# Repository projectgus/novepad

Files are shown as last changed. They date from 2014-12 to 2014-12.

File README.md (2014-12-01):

Development of an adapter board design for [Kosagi Novena](http://kosagi.com/w/index.php?title=Novena_Main_Page) LVDS interface to connect to the "iPad 3" QXGA 2048x1536 eDP LCD panel (aka LG LP097QX1-SPC1 and related models). Possibly also a touch screen interface to suit that display...

* [Schematic PDF here](https://github.com/projectgus/novepad/raw/master/novepad-schematic.pdf)
* [Kosagi forum thread here](http://www.kosagi.com/forums/viewtopic.php?id=58).

**INITIAL PROTOTYPE STAGE, NOT A THING YET**

Very closely modelled on Bunnie's existing Novena eDP adapter, with additions. LVDS connection cable from Novena should be the same on both boards.

Designed using KiCad (2014-07-25, any recent version should be OK to open the files). [Gerbers are available from the releases page](https://github.com/projectgus/novepad/releases/).

# Additions to the Novena eDP design

* Backlight driver (2x TI [TPS61181](http://www.ti.com/product/tps61181))
* Touch screen controller Focaltech [FT5816LPC](http://www.focaltech-systems.com/En/solutions.aspx?CateID=54) with i2c and USB interfaces. There's a strong chance this will never work (lack of public documentation on controller or digitizer).
* 4 eDP lanes out of IT6251 eDP converter instead of the 2 used on Novena eDP board.

# Notes

* Has a lot of numbered test points and 0R resistors due to undocumented or unknown factors.
* Has cut trace jumpers for some key power connections, can be cut to measure power consumption.

# Board Stackup

4 layer board, 1oz copper (35um). Desired stackup is:

* Front copper
* 0.2mm prepreg
* GND (Inner1)
* 1.2mm prepreg
* VCC (Inner2)
* 0.2mm prepreg
* Back

(This matches standard 4 layer stackup for my usual prototype PCB supplier, [Hackvana](http://hackvana.com)).)

The 100 ohm differential microstrip traces (LVDS, eDP) are routed as 0.2mm trace / 0.15mm spacing (~8/6 imperial), at least where possible. This yields estimates in the range of 99.5-102ohm differential impedance depending on who you ask (assuming Er 4.4, calculated using [TNT Field Solver](http://mmtl.sourceforge.net/) and [Jean Nicolle's impedance calculator](http://www.fedevel.com/welldoneblog/2011/08/pcb-impedance-calculator-single-ended-differential-pair/).

# Resources

## Novena designs

Yay OSHW!

* http://kosagi.com/w/index.php?title=Novena_PVT_Design_Source

## iPad display/connectors

* http://emerythacks.blogspot.com.au/2013/04/connecting-ipad-retina-lcd-to-pc.html
* http://mikesmods.com/mm-wp/?s=ipad+3

## Photos of IT6251

You know a chip is going to be fun when **photos** of PCBs that use it become a useful resource to complement the datasheet.

* [overclock.net post with high-res photo of top of board](http://www.overclock.net/t/1225919/yamakasi-catleap-monitor-club/2110#post_16887300)
* [overclock.net lower-res photos incl back of board (no components)](http://www.overclock.net/t/1304102/catleap-q270-replacement-board#post_18163044)

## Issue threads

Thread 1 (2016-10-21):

{Question} Functional?

felixekman, 2016-10-21:
Did you ever get this to work with touch? Can't find a definitive statement about it.

projectgus, 2016-10-21:
No. :( The thread on kosagi forums has some details from back when I was working on it:
http://www.kosagi.com/forums/viewtopic.php?id=58

Summary:

* The Focaltech touch chip doesn't appear to work at all without firmware, which I didn't have. Company & the distributors I found never answered my emails (understandable), and I couldn't find anything suitable in random android file drops, etc.
* I couldn't find any other captouch chips that seemed suitable (in particular, there arelots of touch channels on the ipad3 touch screens).

It's been a couple of years though, so something newer and more suitable might exist now. Another thing to possibly try is to find another model capacitive touch digitiser of the same size, maybe one from a 10 inch Android tablet where the digitiser chip is integrated into the screen unit and it just speaks i2c or something...

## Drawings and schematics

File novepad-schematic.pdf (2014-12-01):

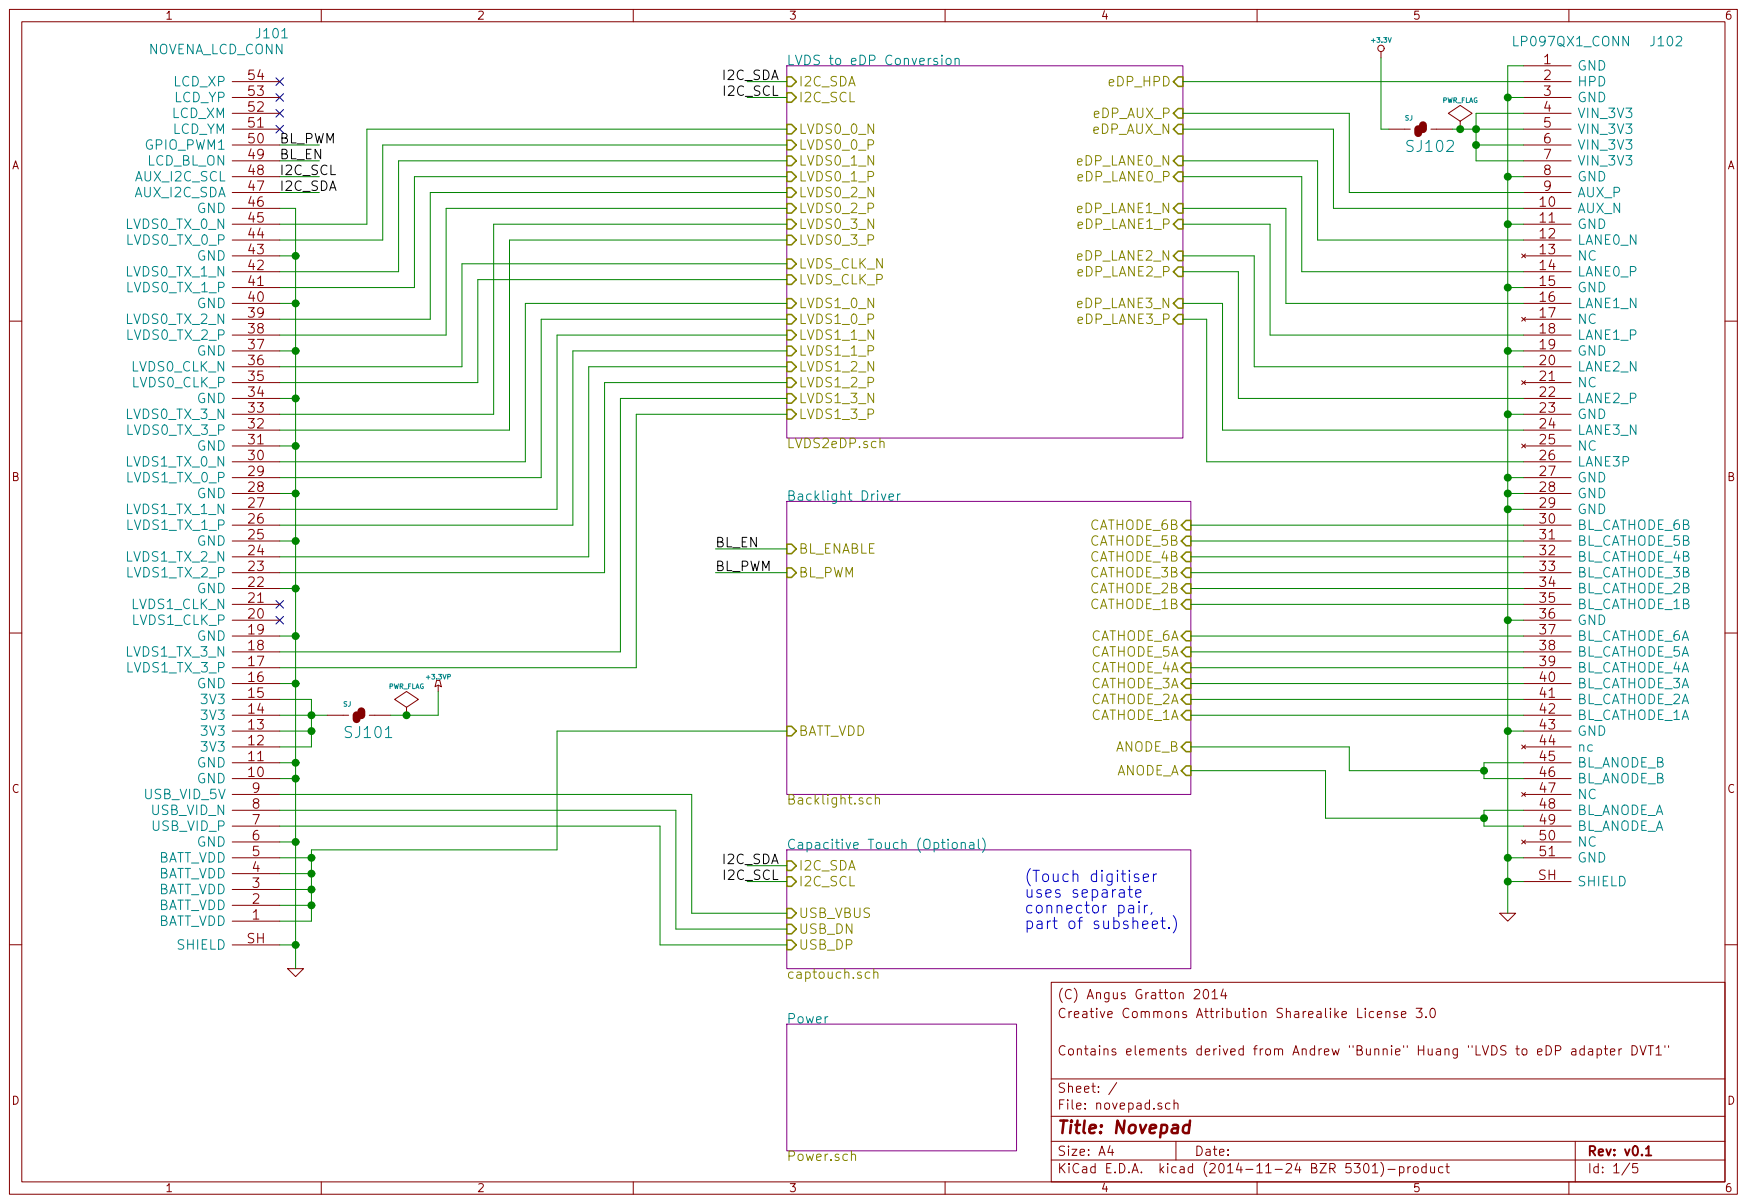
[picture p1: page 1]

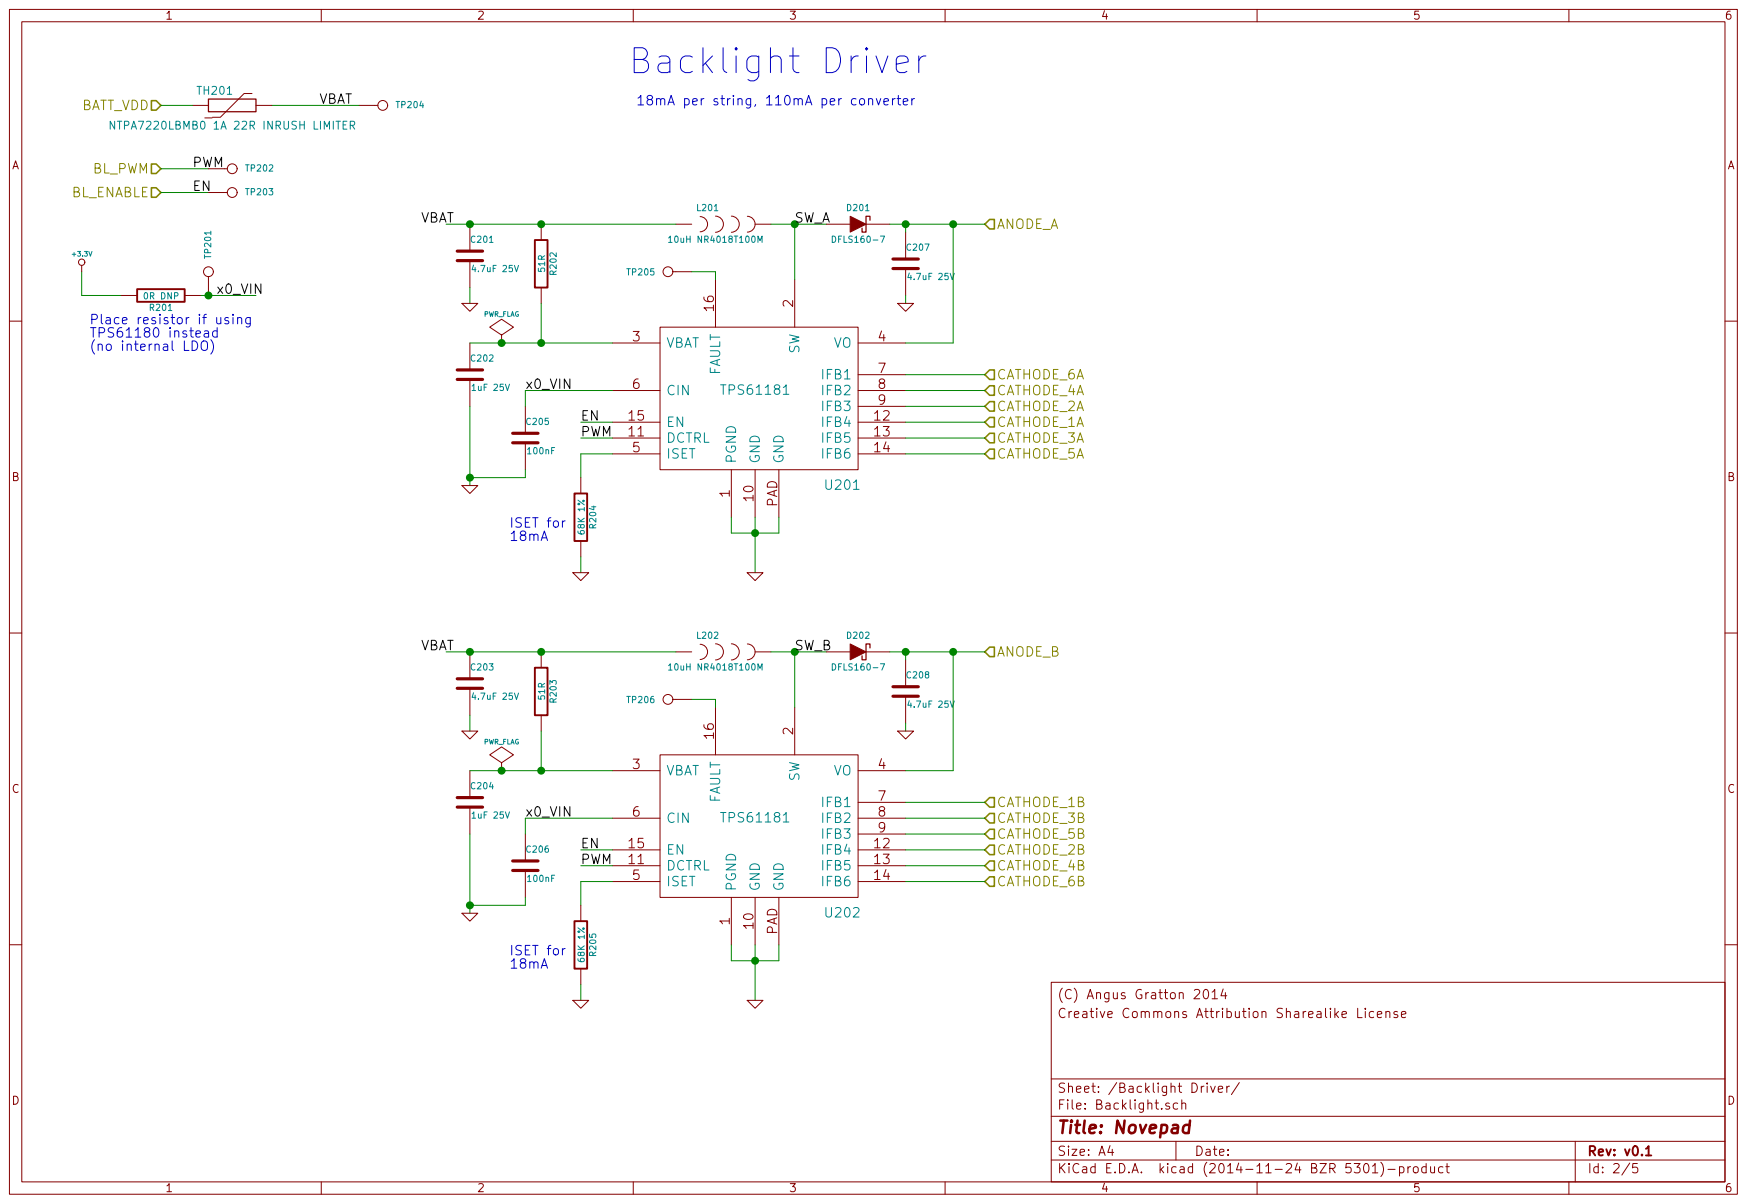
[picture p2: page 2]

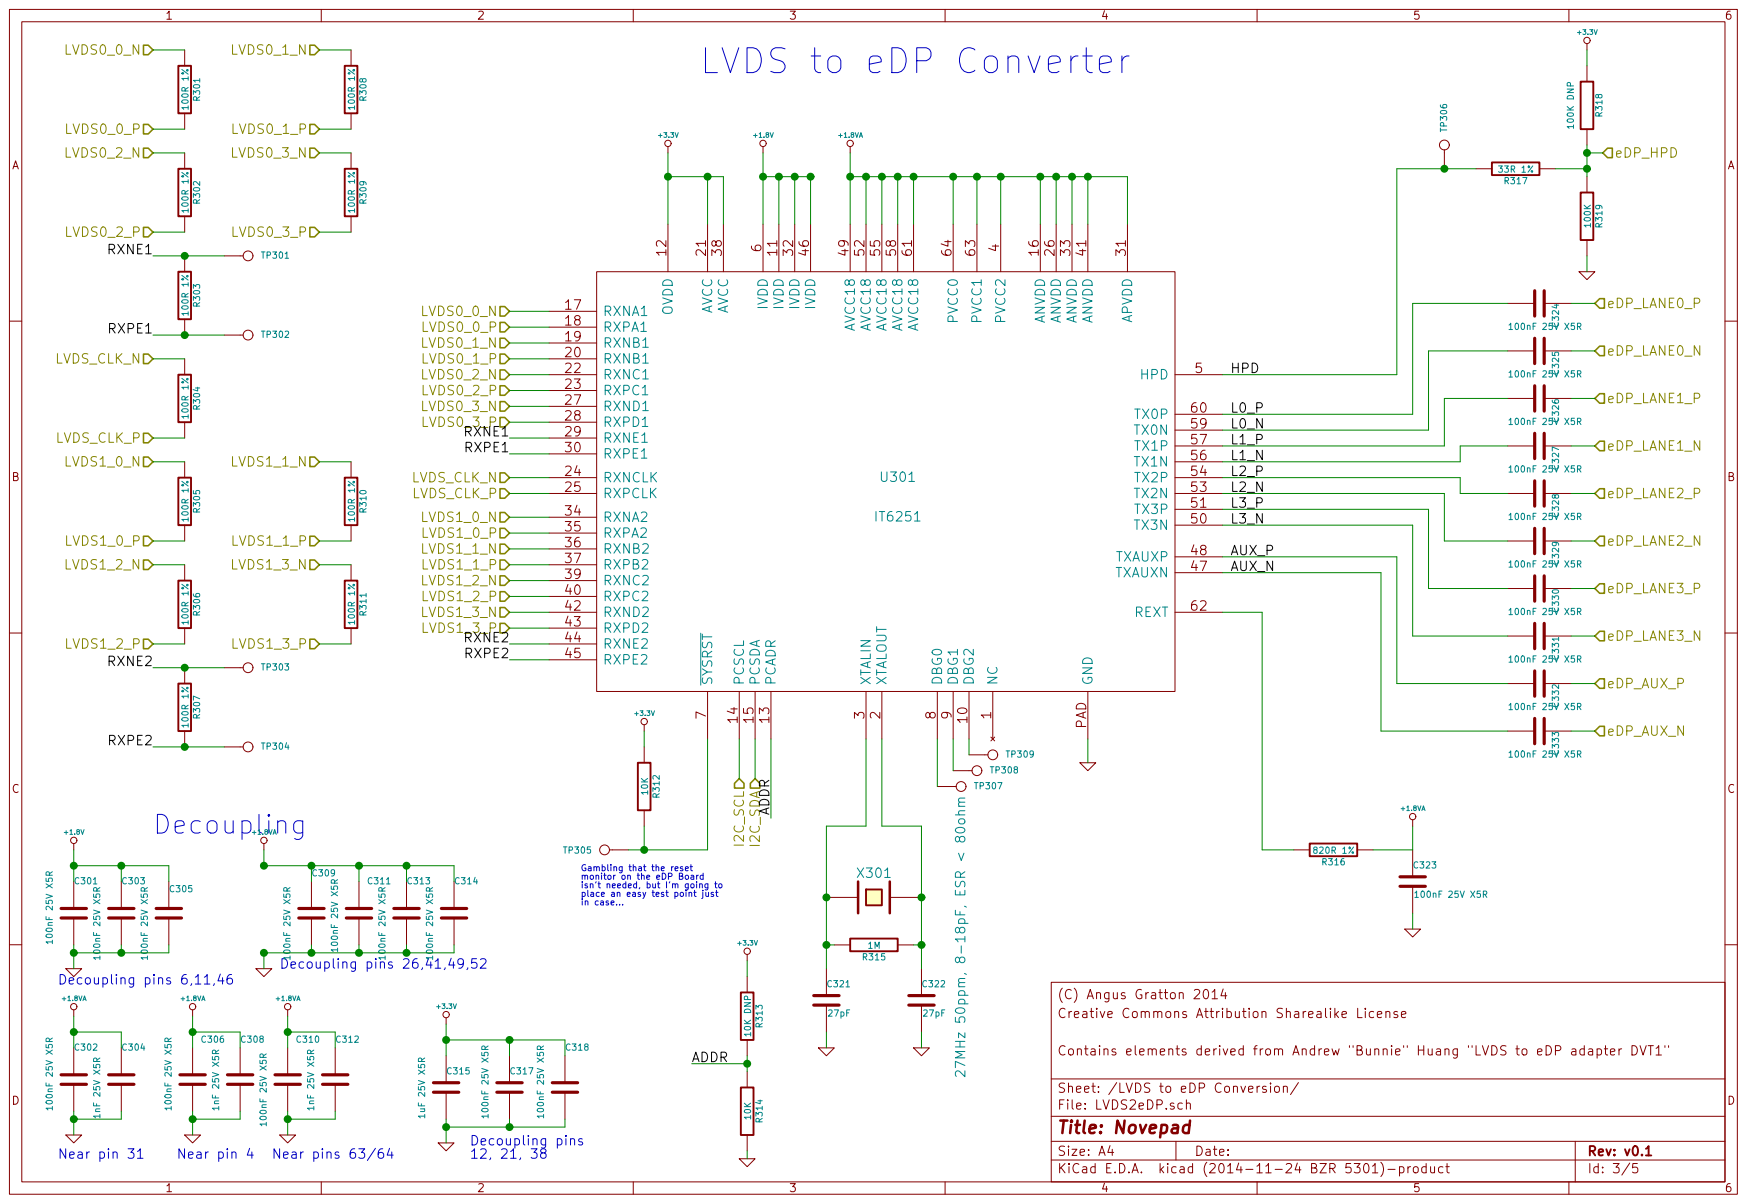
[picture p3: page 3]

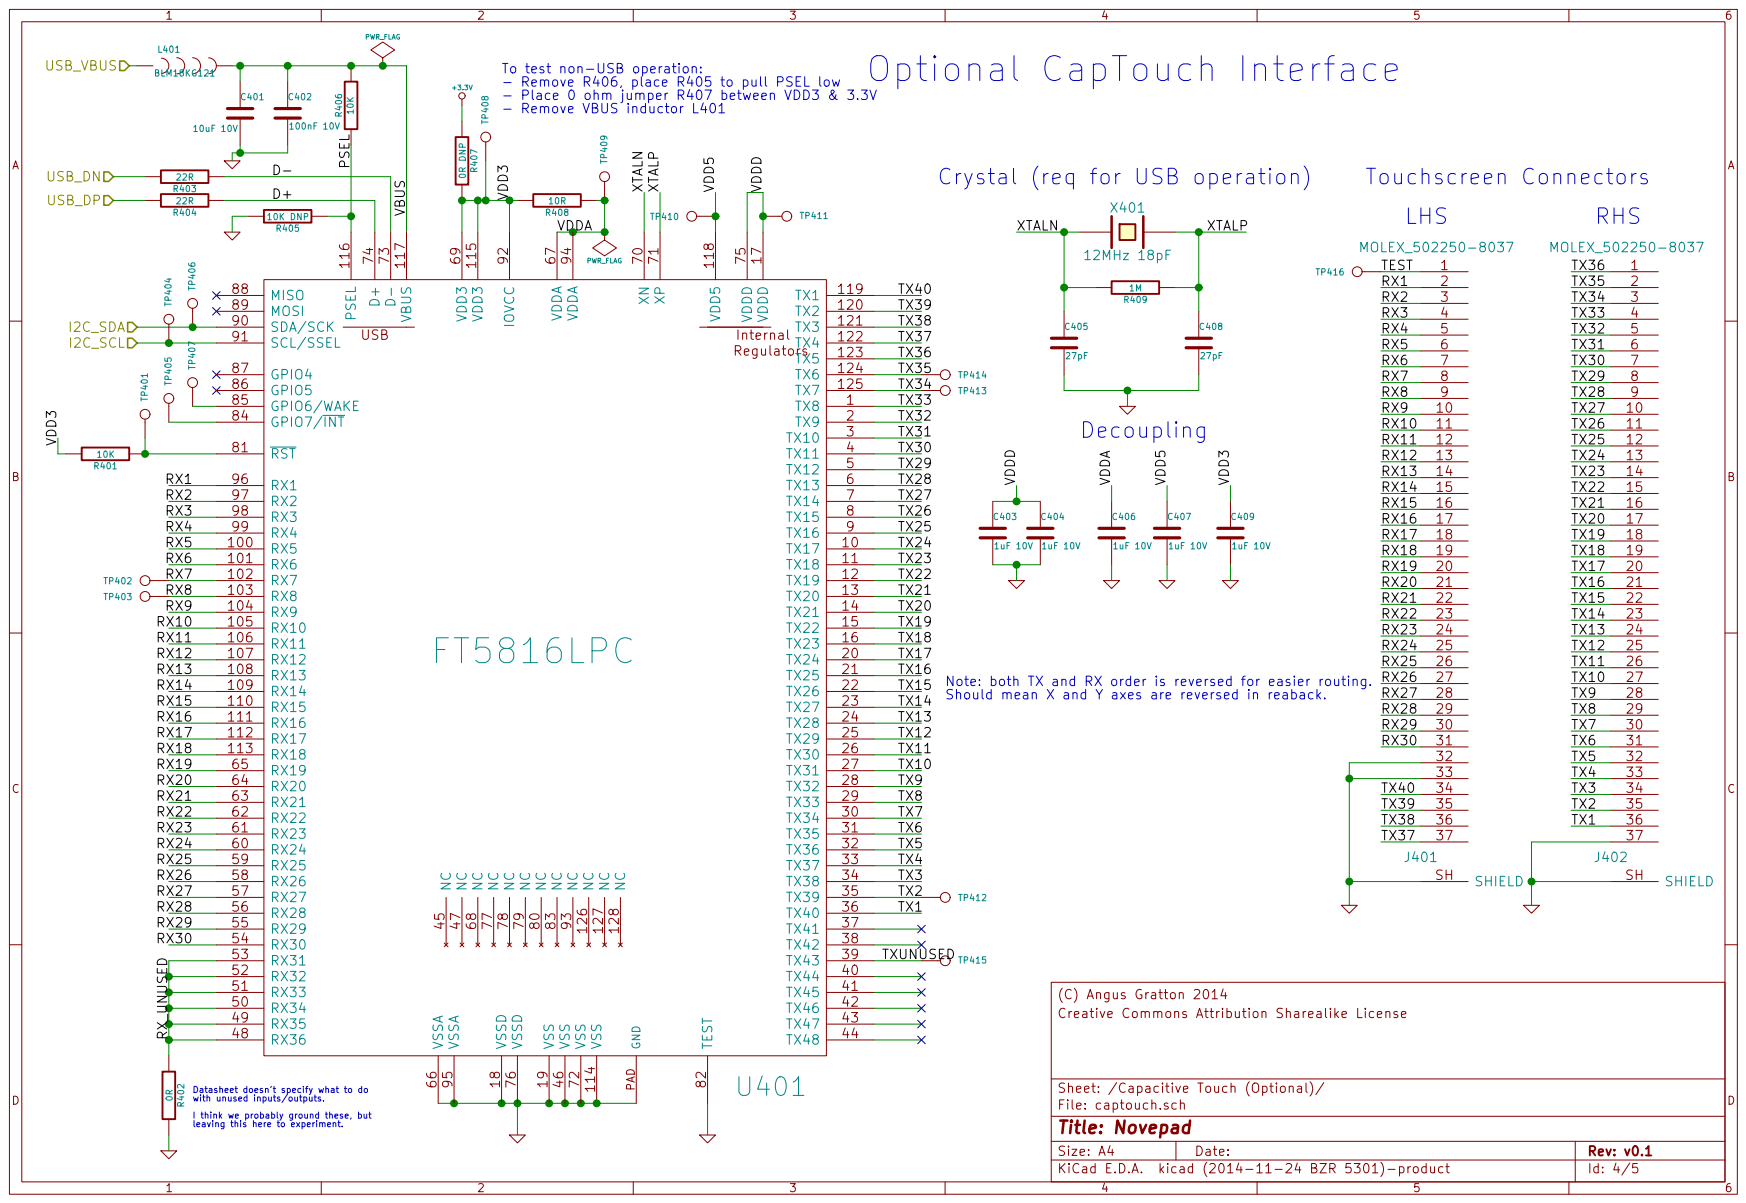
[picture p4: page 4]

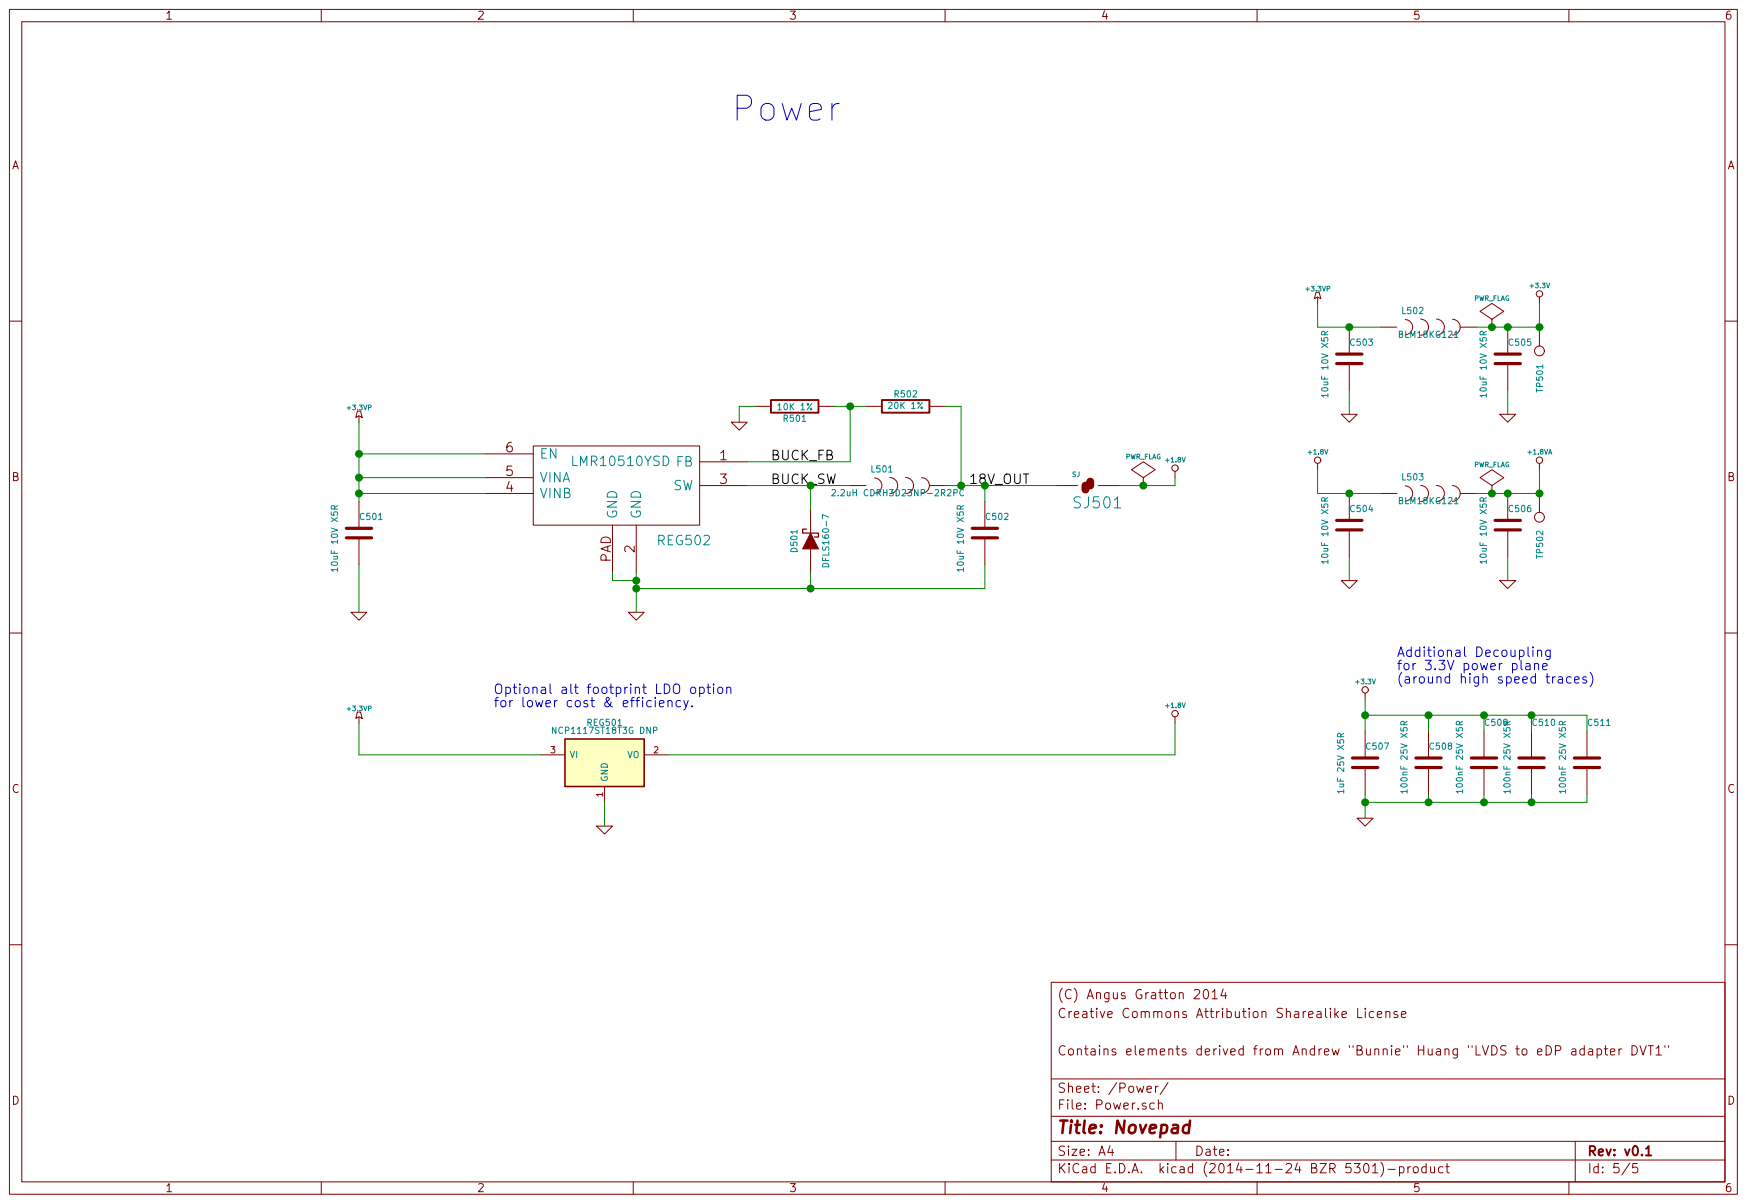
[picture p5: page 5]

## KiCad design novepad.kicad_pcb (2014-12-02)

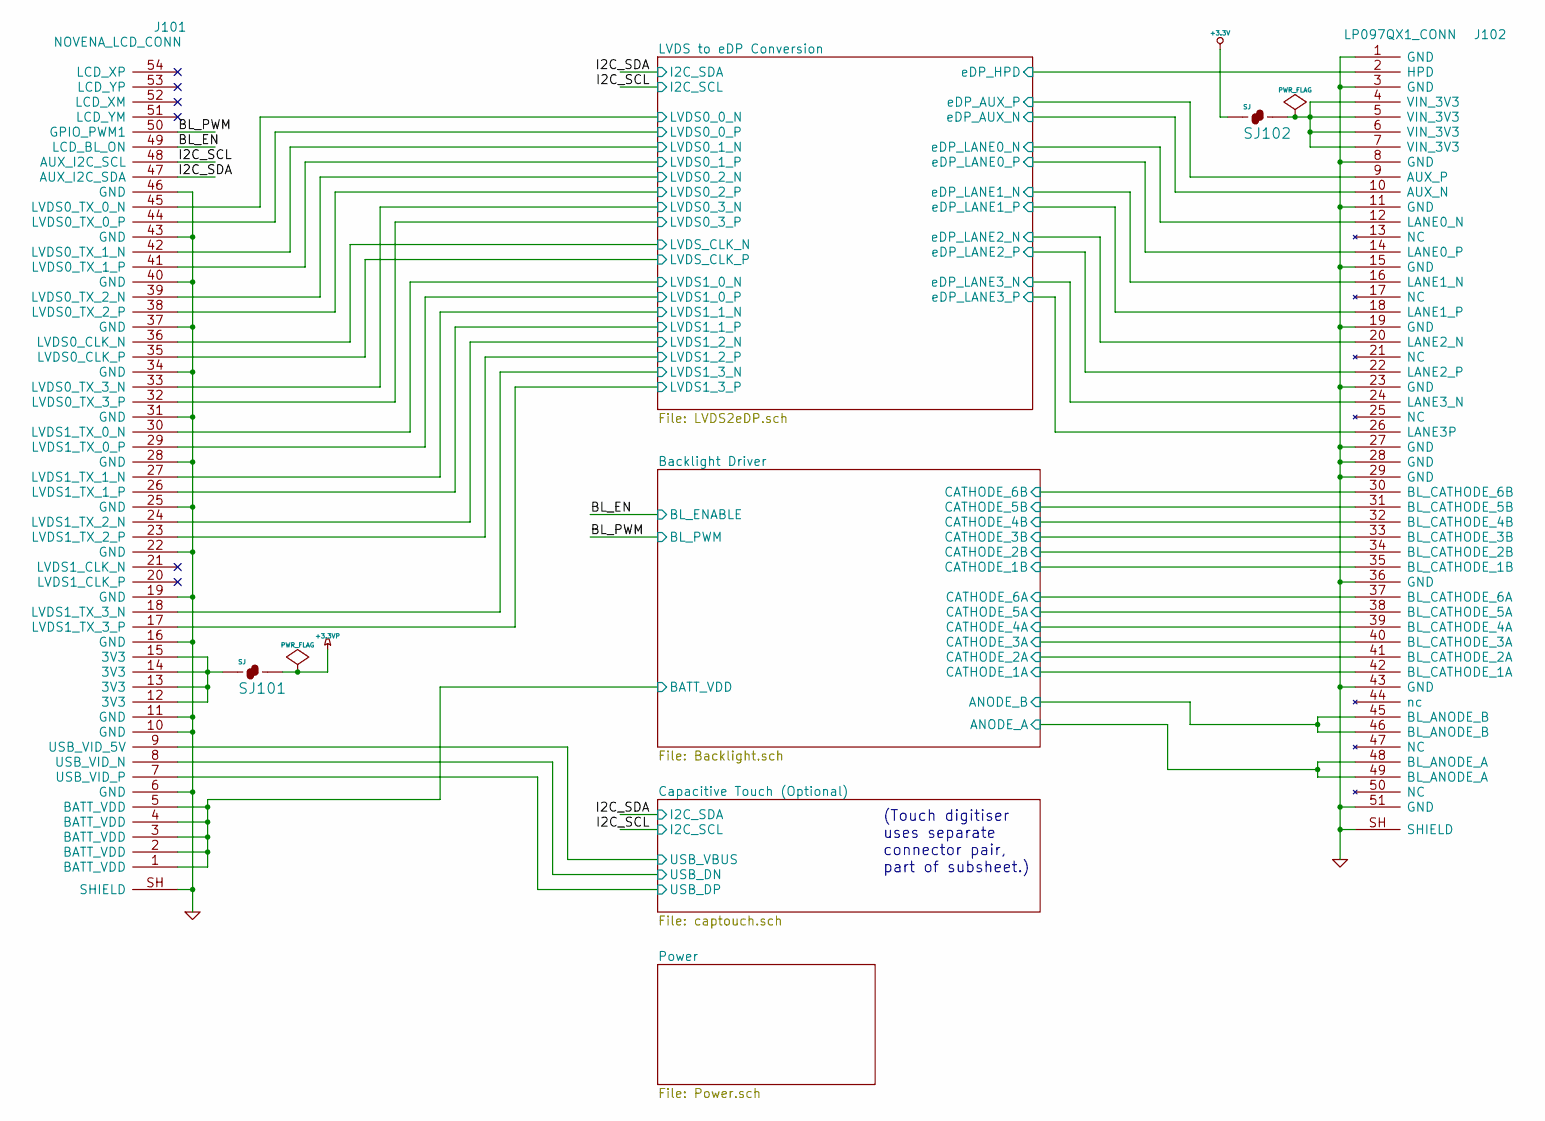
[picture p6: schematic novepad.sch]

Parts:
J101: NOVENA_LCD_CONN; MOLEX_51926_5494
J102: LP097QX1_CONN; MOLEX_502250_8051
SJ101, SJ102: SJ; SJ_SHORTED

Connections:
+3.3V: SJ102.1; also elsewhere on the board
+3.3VP: SJ101.2; also elsewhere on the board
/Backlight Driver/ANODE_A: J102.48 (BL_ANODE_A), J102.49 (BL_ANODE_A); also elsewhere on the board
/Backlight Driver/ANODE_B: J102.45 (BL_ANODE_B), J102.46 (BL_ANODE_B); also elsewhere on the board
/Backlight Driver/BATT_VDD: J101.1 (BATT_VDD), J101.2 (BATT_VDD), J101.3 (BATT_VDD), J101.4 (BATT_VDD), J101.5 (BATT_VDD); also elsewhere on the board
/Backlight Driver/BL_ENABLE: J101.49 (LCD_BL_ON); also elsewhere on the board
/Backlight Driver/BL_PWM: J101.50 (GPIO_PWM1); also elsewhere on the board
/Backlight Driver/CATHODE_1A: J102.42 (BL_CATHODE_1A); also elsewhere on the board
/Backlight Driver/CATHODE_1B: J102.35 (BL_CATHODE_1B); also elsewhere on the board
/Backlight Driver/CATHODE_2A: J102.41 (BL_CATHODE_2A); also elsewhere on the board
/Backlight Driver/CATHODE_2B: J102.34 (BL_CATHODE_2B); also elsewhere on the board
/Backlight Driver/CATHODE_3A: J102.40 (BL_CATHODE_3A); also elsewhere on the board
/Backlight Driver/CATHODE_3B: J102.33 (BL_CATHODE_3B); also elsewhere on the board
/Backlight Driver/CATHODE_4A: J102.39 (BL_CATHODE_4A); also elsewhere on the board
/Backlight Driver/CATHODE_4B: J102.32 (BL_CATHODE_4B); also elsewhere on the board
/Backlight Driver/CATHODE_5A: J102.38 (BL_CATHODE_5A); also elsewhere on the board
/Backlight Driver/CATHODE_5B: J102.31 (BL_CATHODE_5B); also elsewhere on the board
/Backlight Driver/CATHODE_6A: J102.37 (BL_CATHODE_6A); also elsewhere on the board
/Backlight Driver/CATHODE_6B: J102.30 (BL_CATHODE_6B); also elsewhere on the board
/Capacitive Touch (Optional)/I2C_SCL: J101.48 (AUX_I2C_SCL); also elsewhere on the board
/Capacitive Touch (Optional)/I2C_SDA: J101.47 (AUX_I2C_SDA); also elsewhere on the board
/Capacitive Touch (Optional)/USB_DN: J101.8 (USB_VID_N); also elsewhere on the board
/Capacitive Touch (Optional)/USB_DP: J101.7 (USB_VID_P); also elsewhere on the board
/Capacitive Touch (Optional)/USB_VBUS: J101.9 (USB_VID_5V); also elsewhere on the board
/LVDS to eDP Conversion/LVDS0_0_N: J101.45 (LVDS0_TX_0_N); also elsewhere on the board
/LVDS to eDP Conversion/LVDS0_0_P: J101.44 (LVDS0_TX_0_P); also elsewhere on the board
/LVDS to eDP Conversion/LVDS0_1_N: J101.42 (LVDS0_TX_1_N); also elsewhere on the board
/LVDS to eDP Conversion/LVDS0_1_P: J101.41 (LVDS0_TX_1_P); also elsewhere on the board
/LVDS to eDP Conversion/LVDS0_2_N: J101.39 (LVDS0_TX_2_N); also elsewhere on the board
/LVDS to eDP Conversion/LVDS0_2_P: J101.38 (LVDS0_TX_2_P); also elsewhere on the board
/LVDS to eDP Conversion/LVDS0_3_N: J101.33 (LVDS0_TX_3_N); also elsewhere on the board
/LVDS to eDP Conversion/LVDS0_3_P: J101.32 (LVDS0_TX_3_P); also elsewhere on the board
/LVDS to eDP Conversion/LVDS1_0_N: J101.30 (LVDS1_TX_0_N); also elsewhere on the board
/LVDS to eDP Conversion/LVDS1_0_P: J101.29 (LVDS1_TX_0_P); also elsewhere on the board
/LVDS to eDP Conversion/LVDS1_1_N: J101.27 (LVDS1_TX_1_N); also elsewhere on the board
/LVDS to eDP Conversion/LVDS1_1_P: J101.26 (LVDS1_TX_1_P); also elsewhere on the board
/LVDS to eDP Conversion/LVDS1_2_N: J101.24 (LVDS1_TX_2_N); also elsewhere on the board
/LVDS to eDP Conversion/LVDS1_2_P: J101.23 (LVDS1_TX_2_P); also elsewhere on the board
/LVDS to eDP Conversion/LVDS1_3_N: J101.18 (LVDS1_TX_3_N); also elsewhere on the board
/LVDS to eDP Conversion/LVDS1_3_P: J101.17 (LVDS1_TX_3_P); also elsewhere on the board
/LVDS to eDP Conversion/LVDS_CLK_N: J101.36 (LVDS0_CLK_N); also elsewhere on the board
/LVDS to eDP Conversion/LVDS_CLK_P: J101.35 (LVDS0_CLK_P); also elsewhere on the board
/LVDS to eDP Conversion/eDP_AUX_N: J102.10 (AUX_N); also elsewhere on the board
/LVDS to eDP Conversion/eDP_AUX_P: J102.9 (AUX_P); also elsewhere on the board
/LVDS to eDP Conversion/eDP_HPD: J102.2 (HPD); also elsewhere on the board
/LVDS to eDP Conversion/eDP_LANE0_N: J102.12 (LANE0_N); also elsewhere on the board
/LVDS to eDP Conversion/eDP_LANE0_P: J102.14 (LANE0_P); also elsewhere on the board
/LVDS to eDP Conversion/eDP_LANE1_N: J102.16 (LANE1_N); also elsewhere on the board
/LVDS to eDP Conversion/eDP_LANE1_P: J102.18 (LANE1_P); also elsewhere on the board
/LVDS to eDP Conversion/eDP_LANE2_N: J102.20 (LANE2_N); also elsewhere on the board
/LVDS to eDP Conversion/eDP_LANE2_P: J102.22 (LANE2_P); also elsewhere on the board
/LVDS to eDP Conversion/eDP_LANE3_N: J102.24 (LANE3_N); also elsewhere on the board
/LVDS to eDP Conversion/eDP_LANE3_P: J102.26 (LANE3P); also elsewhere on the board
GND: J101.6 (GND), J101.10 (GND), J101.11 (GND), J101.16 (GND), J101.19 (GND), J101.22 (GND), J101.25 (GND), J101.28 (GND), J101.31 (GND), J101.34 (GND), J101.37 (GND), J101.40 (GND), J101.43 (GND), J101.46 (GND), J101.SH (SHIELD), J102.1 (GND), J102.3 (GND), J102.8 (GND), J102.11 (GND), J102.15 (GND), J102.19 (GND), J102.23 (GND), J102.27 (GND), J102.28 (GND), J102.29 (GND), J102.36 (GND), J102.43 (GND), J102.51 (GND), J102.SH (SHIELD); also elsewhere on the board
unnamed: J101.12 (3V3), J101.13 (3V3), J101.14 (3V3), J101.15 (3V3), SJ101.1
unnamed: J102.4 (VIN_3V3), J102.5 (VIN_3V3), J102.6 (VIN_3V3), J102.7 (VIN_3V3), SJ102.2

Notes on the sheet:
(Touch digitiser uses separate connector pair, part of subsheet.)

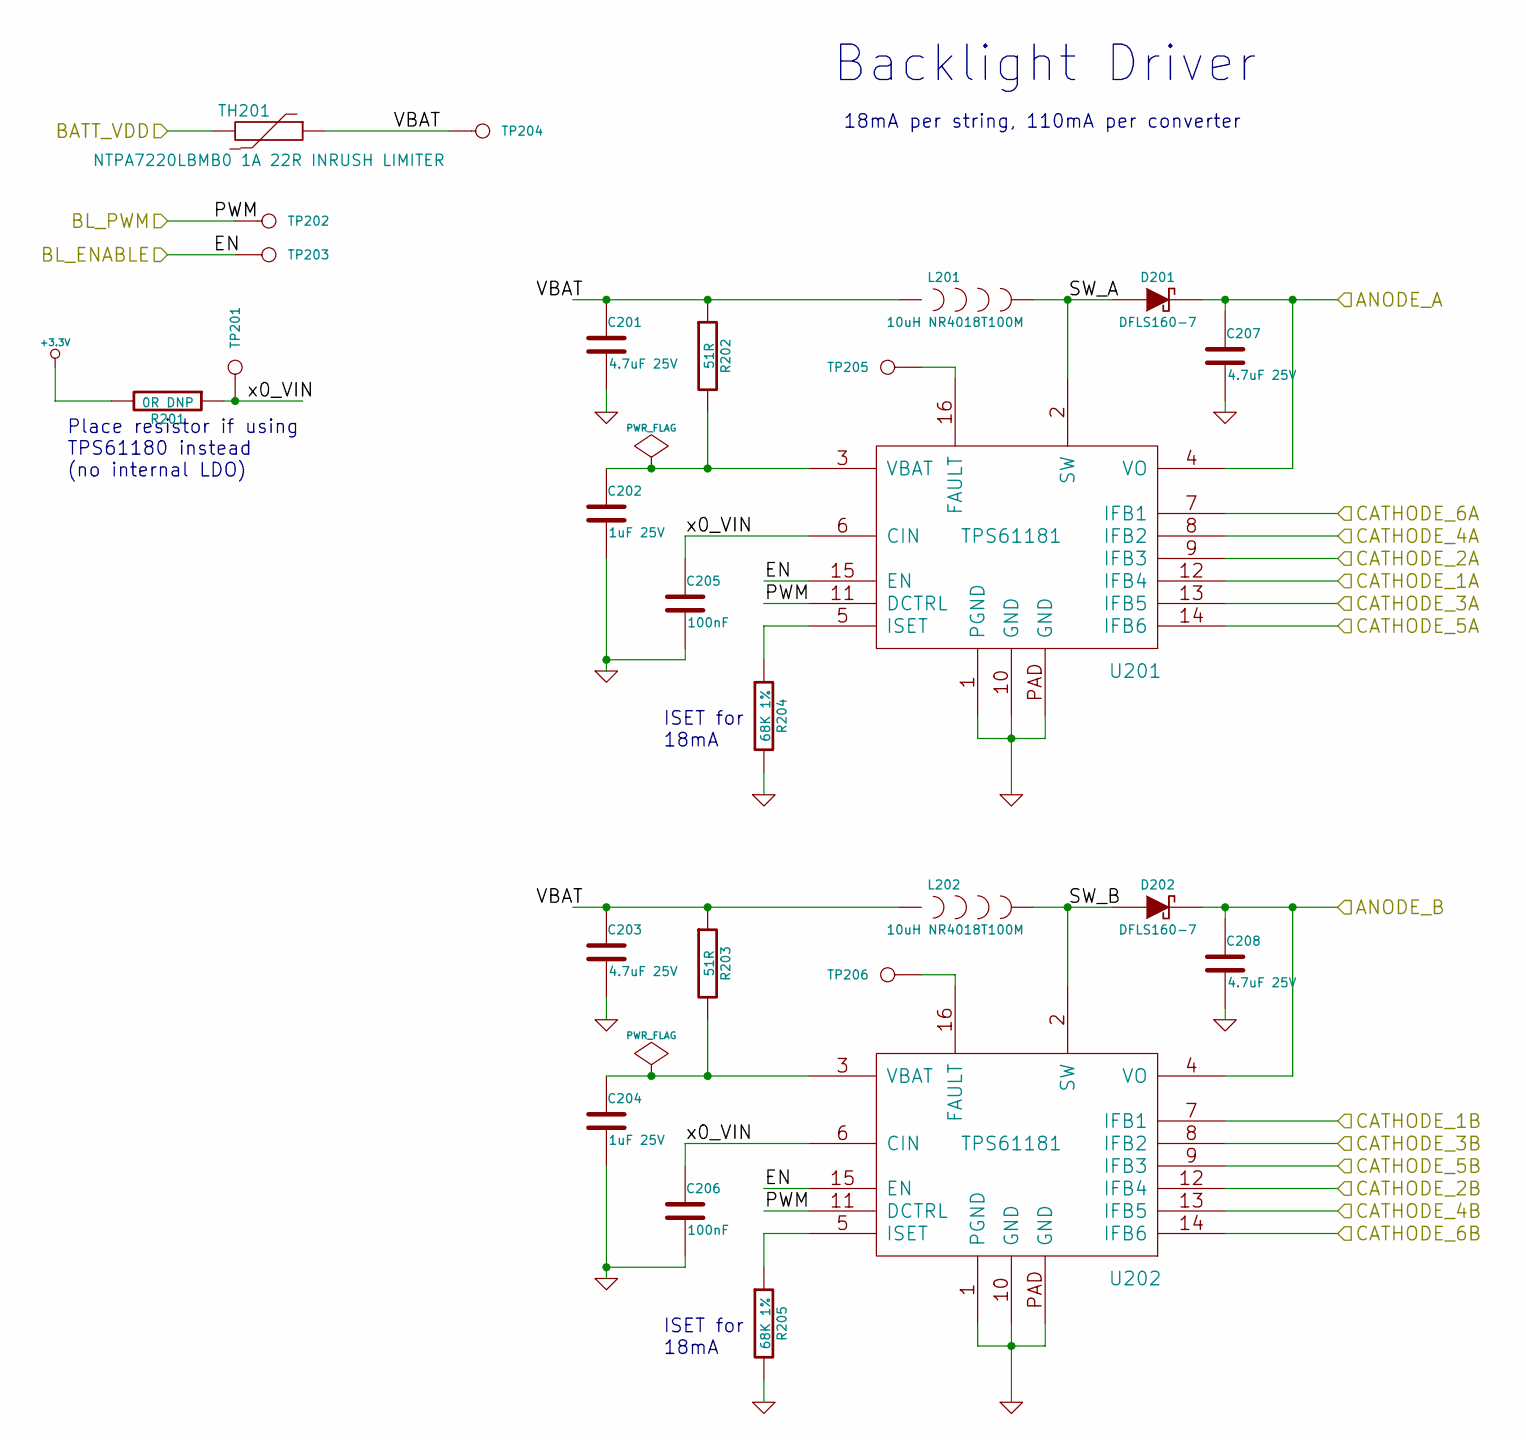
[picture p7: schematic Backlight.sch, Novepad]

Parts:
C201, C203, C207, C208: 4.7uF 25V; 0805
C202, C204: 1uF 25V; 0603
C205, C206: 100nF; C0402
D201, D202: DFLS160-7; POWERDI123_DIODE
L201, L202: 10uH NR4018T100M; NR4018_IND
R201: 0R DNP; 0603
R202, R203: 51R; 0603
R204, R205: 68K 1%; 0603
TH201: NTPA7220LBMB0 1A 22R INRUSH LIMITER; PTH_2HOLE_5MM
TP201, TP202, TP203, TP204, TP205, TP206: CONN_1; SMD_TEST_POINT
U201, U202: TPS61181; QFN50P300X300X80-17N

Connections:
+3.3V: R201.2; also elsewhere on the board
/Backlight Driver/ANODE_A: C207.1, D201.K, U201.4 (VO); also elsewhere on the board
/Backlight Driver/ANODE_B: C208.1, D202.K, U202.4 (VO); also elsewhere on the board
/Backlight Driver/BATT_VDD: TH201.2; also elsewhere on the board
/Backlight Driver/BL_ENABLE: TP203.1, U201.15 (EN), U202.15 (EN); also elsewhere on the board
/Backlight Driver/BL_PWM: TP202.1, U201.11 (DCTRL), U202.11 (DCTRL); also elsewhere on the board
/Backlight Driver/CATHODE_1A: U201.12 (IFB4); also elsewhere on the board
/Backlight Driver/CATHODE_1B: U202.7 (IFB1); also elsewhere on the board
/Backlight Driver/CATHODE_2A: U201.9 (IFB3); also elsewhere on the board
/Backlight Driver/CATHODE_2B: U202.12 (IFB4); also elsewhere on the board
/Backlight Driver/CATHODE_3A: U201.13 (IFB5); also elsewhere on the board
/Backlight Driver/CATHODE_3B: U202.8 (IFB2); also elsewhere on the board
/Backlight Driver/CATHODE_4A: U201.8 (IFB2); also elsewhere on the board
/Backlight Driver/CATHODE_4B: U202.13 (IFB5); also elsewhere on the board
/Backlight Driver/CATHODE_5A: U201.14 (IFB6); also elsewhere on the board
/Backlight Driver/CATHODE_5B: U202.9 (IFB3); also elsewhere on the board
/Backlight Driver/CATHODE_6A: U201.7 (IFB1); also elsewhere on the board
/Backlight Driver/CATHODE_6B: U202.14 (IFB6); also elsewhere on the board
/Backlight Driver/SW_A: D201.A, L201.2, U201.2 (SW)
/Backlight Driver/SW_B: D202.A, L202.2, U202.2 (SW)
/Backlight Driver/VBAT: C201.1, C203.1, L201.1, L202.1, R202.1, R203.1, TH201.1, TP204.1
/Backlight Driver/x0_VIN: C205.1, C206.1, R201.1, TP201.1, U201.6 (CIN), U202.6 (CIN)
GND: C201.2, C202.2, C203.2, C204.2, C205.2, C206.2, C207.2, C208.2, R204.2, R205.2, U201.1 (PGND), U201.10 (GND), U201.PAD (GND), U202.1 (PGND), U202.10 (GND), U202.PAD (GND); also elsewhere on the board
unnamed: C202.1, R202.2, U201.3 (VBAT)
unnamed: C204.1, R203.2, U202.3 (VBAT)
unnamed: R204.1, U201.5 (ISET)
unnamed: R205.1, U202.5 (ISET)
unnamed: TP205.1, U201.16 (FAULT)
unnamed: TP206.1, U202.16 (FAULT)

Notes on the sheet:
Place resistor if using TPS61180 instead (no internal LDO)
18mA per string, 110mA per converter
ISET for 18mA
Backlight Driver

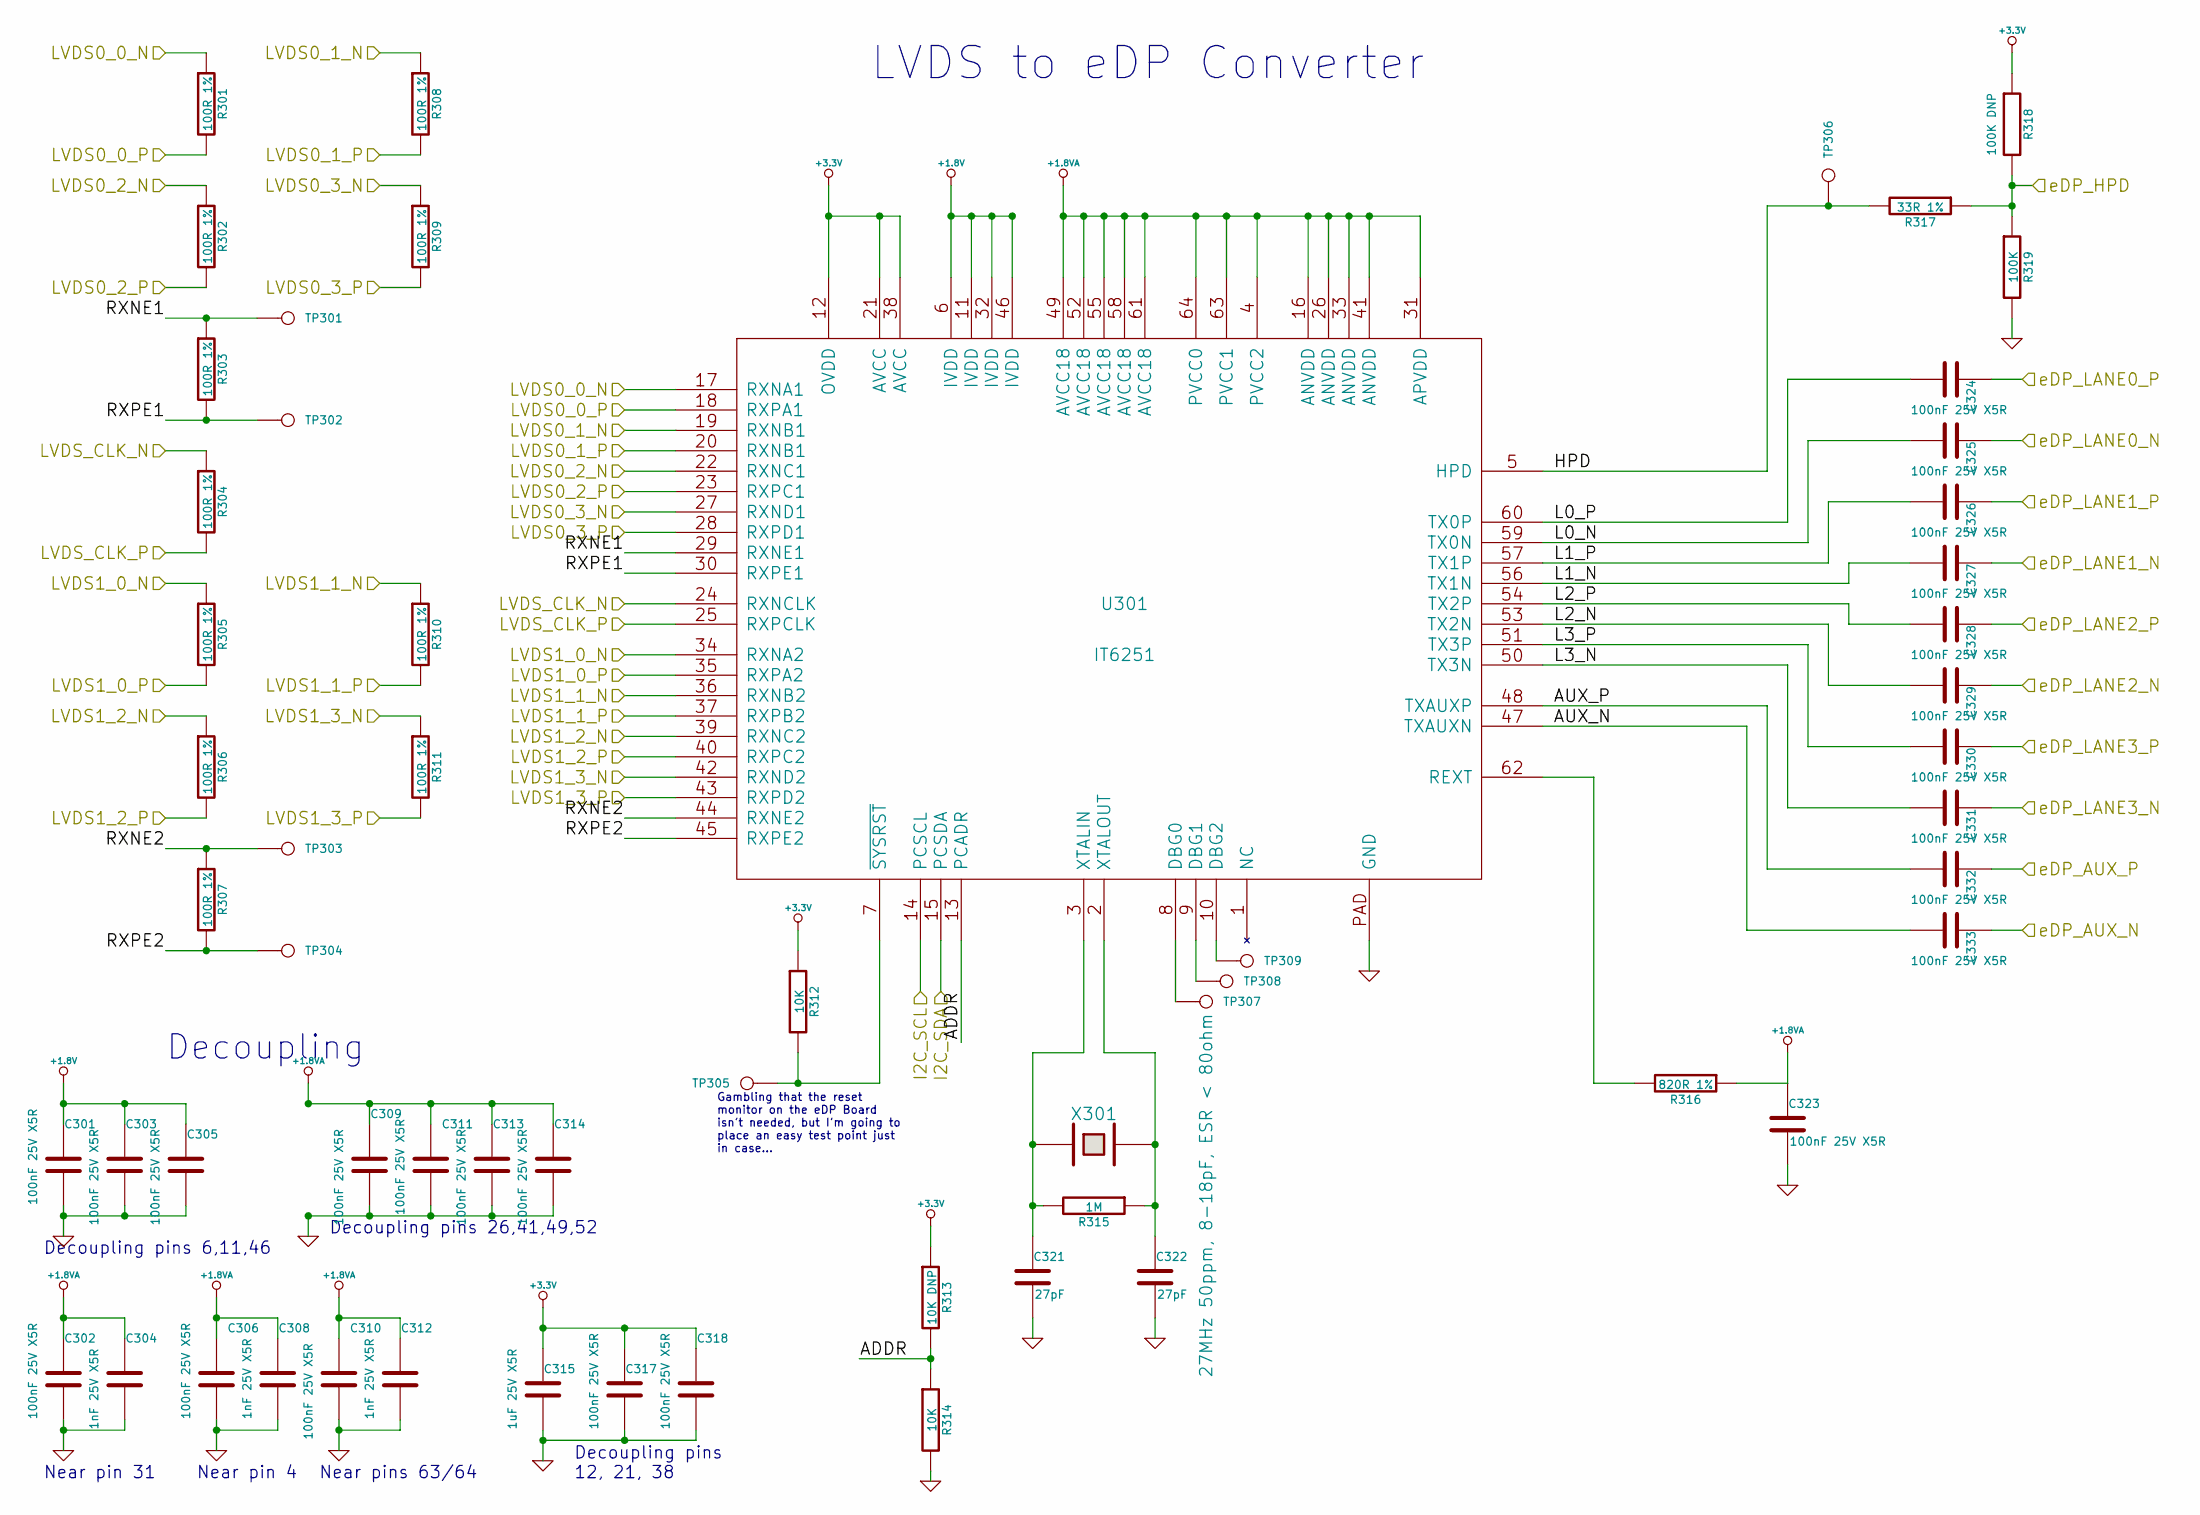
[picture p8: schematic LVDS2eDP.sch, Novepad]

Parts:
C301, C302, C303, C305, C306, C309, C310, C311, C313, C314, C317, C318, C323, C324, C325, C326, C327, C328, C329, C330, C331, C332, C333: 100nF 25V X5R; SMD-0402_c
C304, C308, C312: 1nF 25V X5R; SMD-0402_c
C315: 1uF 25V X5R; SMD-0402_c
C321, C322: 27pF; 0603
R301, R302, R303, R304, R305, R306, R307, R308, R309, R310, R311: 100R 1%; SMD-0402_r
R312, R314: 10K; 0603
R313: 10K DNP; 0603
R315: 1M; 0603
R316: 820R 1%; 0603
R317: 33R 1%; 0603
R318: 100K DNP; 0603
R319: 100K; 0603
TP301, TP302, TP303, TP304, TP305, TP306, TP307, TP308, TP309: CONN_1; SMD_TEST_POINT
U301: IT6251; QFN50P900X900X100-65N
X301: 27MHz 50ppm, 8-18pF, ESR < 80ohm; HC49UP

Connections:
+1.8V: C301.1, C303.1, C305.1, U301.6 (IVDD), U301.11 (IVDD), U301.32 (IVDD), U301.46 (IVDD); also elsewhere on the board
+1.8VA: C302.1, C304.1, C306.1, C308.1, C309.1, C310.1, C311.1, C312.1, C313.1, C314.1, C323.1, R316.1, U301.4 (PVCC2), U301.16 (ANVDD), U301.26 (ANVDD), U301.31 (APVDD), U301.33 (ANVDD), U301.41 (ANVDD), U301.49 (AVCC18), U301.52 (AVCC18), U301.55 (AVCC18), U301.58 (AVCC18), U301.61 (AVCC18), U301.63 (PVCC1), U301.64 (PVCC0); also elsewhere on the board
+3.3V: C315.1, C317.1, C318.1, R312.1, R313.1, R318.1, U301.12 (OVDD), U301.21 (AVCC), U301.38 (AVCC); also elsewhere on the board
/Capacitive Touch (Optional)/I2C_SCL: U301.14 (PCSCL); also elsewhere on the board
/Capacitive Touch (Optional)/I2C_SDA: U301.15 (PCSDA); also elsewhere on the board
/LVDS to eDP Conversion/ADDR: R313.2, R314.1, U301.13 (PCADR)
/LVDS to eDP Conversion/AUX_N: C333.2, U301.47 (TXAUXN)
/LVDS to eDP Conversion/AUX_P: C332.2, U301.48 (TXAUXP)
/LVDS to eDP Conversion/HPD: R317.2, TP306.1, U301.5 (HPD)
/LVDS to eDP Conversion/L0_N: C325.2, U301.59 (TX0N)
/LVDS to eDP Conversion/L0_P: C324.2, U301.60 (TX0P)
/LVDS to eDP Conversion/L1_N: C327.2, U301.56 (TX1N)
/LVDS to eDP Conversion/L1_P: C326.2, U301.57 (TX1P)
/LVDS to eDP Conversion/L2_N: C329.2, U301.53 (TX2N)
/LVDS to eDP Conversion/L2_P: C328.2, U301.54 (TX2P)
/LVDS to eDP Conversion/L3_N: C331.2, U301.50 (TX3N)
/LVDS to eDP Conversion/L3_P: C330.2, U301.51 (TX3P)
/LVDS to eDP Conversion/LVDS0_0_N: R301.1, U301.17 (RXNA1); also elsewhere on the board
/LVDS to eDP Conversion/LVDS0_0_P: R301.2, U301.18 (RXPA1); also elsewhere on the board
/LVDS to eDP Conversion/LVDS0_1_N: R308.1, U301.19 (RXNB1); also elsewhere on the board
/LVDS to eDP Conversion/LVDS0_1_P: R308.2, U301.20 (RXNB1); also elsewhere on the board
/LVDS to eDP Conversion/LVDS0_2_N: R302.1, U301.22 (RXNC1); also elsewhere on the board
/LVDS to eDP Conversion/LVDS0_2_P: R302.2, U301.23 (RXPC1); also elsewhere on the board
/LVDS to eDP Conversion/LVDS0_3_N: R309.1, U301.27 (RXND1); also elsewhere on the board
/LVDS to eDP Conversion/LVDS0_3_P: R309.2, U301.28 (RXPD1); also elsewhere on the board
/LVDS to eDP Conversion/LVDS1_0_N: R305.1, U301.34 (RXNA2); also elsewhere on the board
/LVDS to eDP Conversion/LVDS1_0_P: R305.2, U301.35 (RXPA2); also elsewhere on the board
/LVDS to eDP Conversion/LVDS1_1_N: R310.1, U301.36 (RXNB2); also elsewhere on the board
/LVDS to eDP Conversion/LVDS1_1_P: R310.2, U301.37 (RXPB2); also elsewhere on the board
/LVDS to eDP Conversion/LVDS1_2_N: R306.1, U301.39 (RXNC2); also elsewhere on the board
/LVDS to eDP Conversion/LVDS1_2_P: R306.2, U301.40 (RXPC2); also elsewhere on the board
/LVDS to eDP Conversion/LVDS1_3_N: R311.1, U301.42 (RXND2); also elsewhere on the board
/LVDS to eDP Conversion/LVDS1_3_P: R311.2, U301.43 (RXPD2); also elsewhere on the board
/LVDS to eDP Conversion/LVDS_CLK_N: R304.1, U301.24 (RXNCLK); also elsewhere on the board
/LVDS to eDP Conversion/LVDS_CLK_P: R304.2, U301.25 (RXPCLK); also elsewhere on the board
/LVDS to eDP Conversion/RXNE1: R303.1, TP301.1, U301.29 (RXNE1)
/LVDS to eDP Conversion/RXNE2: R307.1, TP303.1, U301.44 (RXNE2)
/LVDS to eDP Conversion/RXPE1: R303.2, TP302.1, U301.30 (RXPE1)
/LVDS to eDP Conversion/RXPE2: R307.2, TP304.1, U301.45 (RXPE2)
/LVDS to eDP Conversion/eDP_AUX_N: C333.1; also elsewhere on the board
/LVDS to eDP Conversion/eDP_AUX_P: C332.1; also elsewhere on the board
/LVDS to eDP Conversion/eDP_HPD: R317.1, R318.2, R319.1; also elsewhere on the board
/LVDS to eDP Conversion/eDP_LANE0_N: C325.1; also elsewhere on the board
/LVDS to eDP Conversion/eDP_LANE0_P: C324.1; also elsewhere on the board
/LVDS to eDP Conversion/eDP_LANE1_N: C327.1; also elsewhere on the board
/LVDS to eDP Conversion/eDP_LANE1_P: C326.1; also elsewhere on the board
/LVDS to eDP Conversion/eDP_LANE2_N: C329.1; also elsewhere on the board
/LVDS to eDP Conversion/eDP_LANE2_P: C328.1; also elsewhere on the board
/LVDS to eDP Conversion/eDP_LANE3_N: C331.1; also elsewhere on the board
/LVDS to eDP Conversion/eDP_LANE3_P: C330.1; also elsewhere on the board
GND: C301.2, C302.2, C303.2, C304.2, C305.2, C306.2, C308.2, C309.2, C310.2, C311.2, C312.2, C313.2, C314.2, C315.2, C317.2, C318.2, C321.2, C322.2, C323.2, R314.2, R319.2, U301.PAD (GND); also elsewhere on the board
unnamed: C321.1, R315.2, U301.3 (XTALIN), X301.1
unnamed: C322.1, R315.1, U301.2 (XTALOUT), X301.2
unnamed: R312.2, TP305.1, U301.7 (~SYSRST)
unnamed: R316.2, U301.62 (REXT)
unnamed: TP307.1, U301.8 (DBG0)
unnamed: TP308.1, U301.9 (DBG1)
unnamed: TP309.1, U301.10 (DBG2)

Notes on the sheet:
Gambling that the reset monitor on the eDP Board isn't needed, but I'm going to place an easy test point just in case...
Decoupling pins 12, 21, 38
Decoupling pins 26,41,49,52
Near pin 31
Near pin 4
Decoupling
Near pins 63/64
LVDS to eDP Converter
Decoupling pins 6,11,46

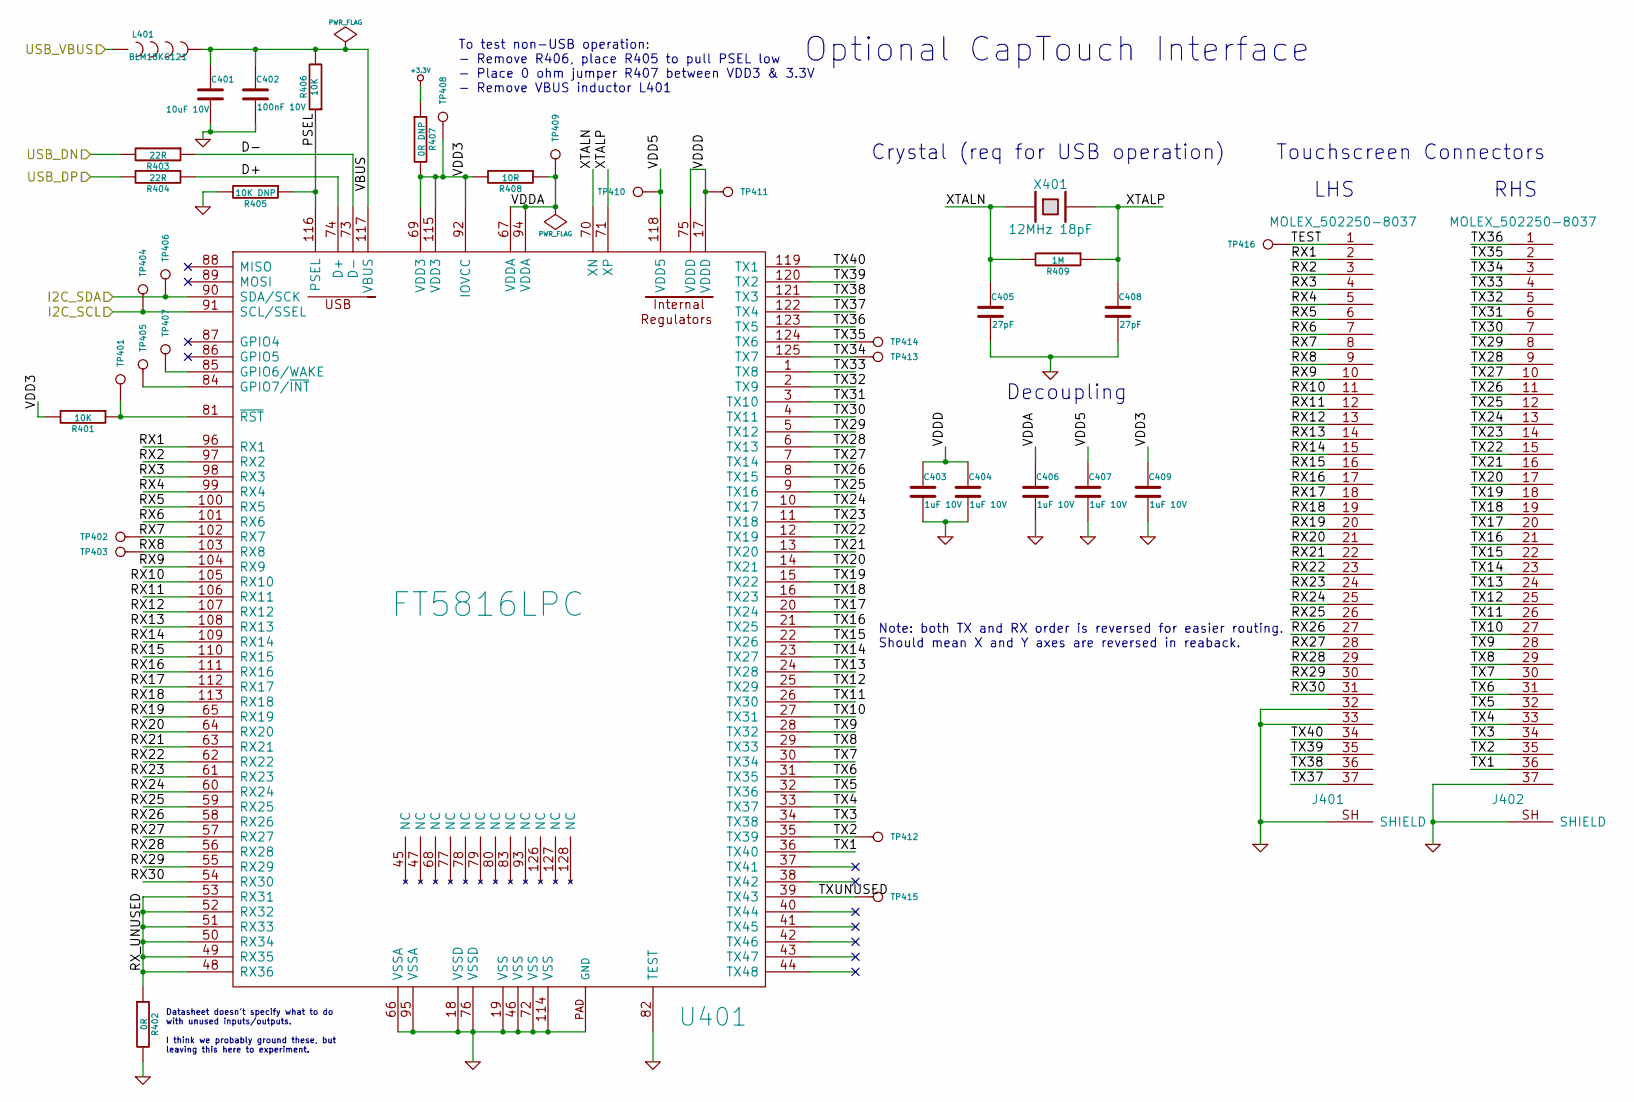
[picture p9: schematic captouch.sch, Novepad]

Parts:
C401: 10uF 10V; 1206
C402: 100nF 10V; C0402
C403, C404, C406, C407, C409: 1uF 10V; 0603
C405, C408: 27pF; 0603
J401, J402: MOLEX_502250-8037; MOLEX_502250_8037
L401: BLM18KG121; 0603
R401, R406: 10K; 0603
R402: 0R; 0603
R403, R404: 22R; 0603
R405: 10K DNP; 0603
R407: 0R DNP; 0603
R408: 10R; 0603
R409: 1M; 0603
TP401, TP402, TP403, TP404, TP405, TP406, TP407, TP408, TP409, TP410, TP411, TP412, TP413, TP414, TP415, TP416: CONN_1; SMD_TEST_POINT
U401: FT5816LPC; QFP40P1600X1600X100-129N
X401: 12MHz 18pF; HC49UP

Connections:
+3.3V: R407.1; also elsewhere on the board
/Capacitive Touch (Optional)/D+: R404.1, U401.74 (D+)
/Capacitive Touch (Optional)/D-: R403.1, U401.73 (D-)
/Capacitive Touch (Optional)/I2C_SCL: TP404.1, U401.91 (SCL/SSEL); also elsewhere on the board
/Capacitive Touch (Optional)/I2C_SDA: TP406.1, U401.90 (SDA/SCK); also elsewhere on the board
/Capacitive Touch (Optional)/PSEL: R405.1, R406.1, U401.116 (PSEL)
/Capacitive Touch (Optional)/RX1: J401.2, U401.96 (RX1)
/Capacitive Touch (Optional)/RX2: J401.3, U401.97 (RX2)
/Capacitive Touch (Optional)/RX3: J401.4, U401.98 (RX3)
/Capacitive Touch (Optional)/RX4: J401.5, U401.99 (RX4)
/Capacitive Touch (Optional)/RX5: J401.6, U401.100 (RX5)
/Capacitive Touch (Optional)/RX6: J401.7, U401.101 (RX6)
/Capacitive Touch (Optional)/RX7: J401.8, TP402.1, U401.102 (RX7)
/Capacitive Touch (Optional)/RX8: J401.9, TP403.1, U401.103 (RX8)
/Capacitive Touch (Optional)/RX9: J401.10, U401.104 (RX9)
/Capacitive Touch (Optional)/RX10: J401.11, U401.105 (RX10)
/Capacitive Touch (Optional)/RX11: J401.12, U401.106 (RX11)
/Capacitive Touch (Optional)/RX12: J401.13, U401.107 (RX12)
/Capacitive Touch (Optional)/RX13: J401.14, U401.108 (RX13)
/Capacitive Touch (Optional)/RX14: J401.15, U401.109 (RX14)
/Capacitive Touch (Optional)/RX15: J401.16, U401.110 (RX15)
/Capacitive Touch (Optional)/RX16: J401.17, U401.111 (RX16)
/Capacitive Touch (Optional)/RX17: J401.18, U401.112 (RX17)
/Capacitive Touch (Optional)/RX18: J401.19, U401.113 (RX18)
/Capacitive Touch (Optional)/RX19: J401.20, U401.65 (RX19)
/Capacitive Touch (Optional)/RX20: J401.21, U401.64 (RX20)
/Capacitive Touch (Optional)/RX21: J401.22, U401.63 (RX21)
/Capacitive Touch (Optional)/RX22: J401.23, U401.62 (RX22)
/Capacitive Touch (Optional)/RX23: J401.24, U401.61 (RX23)
/Capacitive Touch (Optional)/RX24: J401.25, U401.60 (RX24)
/Capacitive Touch (Optional)/RX25: J401.26, U401.59 (RX25)
/Capacitive Touch (Optional)/RX26: J401.27, U401.58 (RX26)
/Capacitive Touch (Optional)/RX27: J401.28, U401.57 (RX27)
/Capacitive Touch (Optional)/RX28: J401.29, U401.56 (RX28)
/Capacitive Touch (Optional)/RX29: J401.30, U401.55 (RX29)
/Capacitive Touch (Optional)/RX30: J401.31, U401.54 (RX30)
/Capacitive Touch (Optional)/RX_UNUSED: R402.1, U401.48 (RX36), U401.49 (RX35), U401.50 (RX34), U401.51 (RX33), U401.52 (RX32), U401.53 (RX31)
/Capacitive Touch (Optional)/TEST: J401.1, TP416.1
/Capacitive Touch (Optional)/TX1: J402.36, U401.36 (TX40)
/Capacitive Touch (Optional)/TX2: J402.35, TP412.1, U401.35 (TX39)
/Capacitive Touch (Optional)/TX3: J402.34, U401.34 (TX38)
/Capacitive Touch (Optional)/TX4: J402.33, U401.33 (TX37)
/Capacitive Touch (Optional)/TX5: J402.32, U401.32 (TX36)
/Capacitive Touch (Optional)/TX6: J402.31, U401.31 (TX35)
/Capacitive Touch (Optional)/TX7: J402.30, U401.30 (TX34)
/Capacitive Touch (Optional)/TX8: J402.29, U401.29 (TX33)
/Capacitive Touch (Optional)/TX9: J402.28, U401.28 (TX32)
/Capacitive Touch (Optional)/TX10: J402.27, U401.27 (TX31)
/Capacitive Touch (Optional)/TX11: J402.26, U401.26 (TX30)
/Capacitive Touch (Optional)/TX12: J402.25, U401.25 (TX29)
/Capacitive Touch (Optional)/TX13: J402.24, U401.24 (TX28)
/Capacitive Touch (Optional)/TX14: J402.23, U401.23 (TX27)
/Capacitive Touch (Optional)/TX15: J402.22, U401.22 (TX26)
/Capacitive Touch (Optional)/TX16: J402.21, U401.21 (TX25)
/Capacitive Touch (Optional)/TX17: J402.20, U401.20 (TX24)
/Capacitive Touch (Optional)/TX18: J402.19, U401.16 (TX23)
/Capacitive Touch (Optional)/TX19: J402.18, U401.15 (TX22)
/Capacitive Touch (Optional)/TX20: J402.17, U401.14 (TX21)
/Capacitive Touch (Optional)/TX21: J402.16, U401.13 (TX20)
/Capacitive Touch (Optional)/TX22: J402.15, U401.12 (TX19)
/Capacitive Touch (Optional)/TX23: J402.14, U401.11 (TX18)
/Capacitive Touch (Optional)/TX24: J402.13, U401.10 (TX17)
/Capacitive Touch (Optional)/TX25: J402.12, U401.9 (TX16)
/Capacitive Touch (Optional)/TX26: J402.11, U401.8 (TX15)
/Capacitive Touch (Optional)/TX27: J402.10, U401.7 (TX14)
/Capacitive Touch (Optional)/TX28: J402.9, U401.6 (TX13)
/Capacitive Touch (Optional)/TX29: J402.8, U401.5 (TX12)
/Capacitive Touch (Optional)/TX30: J402.7, U401.4 (TX11)
/Capacitive Touch (Optional)/TX31: J402.6, U401.3 (TX10)
/Capacitive Touch (Optional)/TX32: J402.5, U401.2 (TX9)
/Capacitive Touch (Optional)/TX33: J402.4, U401.1 (TX8)
/Capacitive Touch (Optional)/TX34: J402.3, TP413.1, U401.125 (TX7)
/Capacitive Touch (Optional)/TX35: J402.2, TP414.1, U401.124 (TX6)
/Capacitive Touch (Optional)/TX36: J402.1, U401.123 (TX5)
/Capacitive Touch (Optional)/TX37: J401.37, U401.122 (TX4)
/Capacitive Touch (Optional)/TX38: J401.36, U401.121 (TX3)
/Capacitive Touch (Optional)/TX39: J401.35, U401.120 (TX2)
/Capacitive Touch (Optional)/TX40: J401.34, U401.119 (TX1)
/Capacitive Touch (Optional)/TXUNUSED: TP415.1, U401.39 (TX43)
/Capacitive Touch (Optional)/USB_DN: R403.2; also elsewhere on the board
/Capacitive Touch (Optional)/USB_DP: R404.2; also elsewhere on the board
/Capacitive Touch (Optional)/USB_VBUS: L401.1; also elsewhere on the board
/Capacitive Touch (Optional)/VBUS: C401.1, C402.1, L401.2, R406.2, U401.117 (VBUS)
/Capacitive Touch (Optional)/VDD3: C409.1, R401.2, R407.2, R408.2, TP408.1, U401.69 (VDD3), U401.92 (IOVCC), U401.115 (VDD3)
/Capacitive Touch (Optional)/VDD5: C407.1, TP410.1, U401.118 (VDD5)
/Capacitive Touch (Optional)/VDDA: C406.1, R408.1, TP409.1, U401.67 (VDDA), U401.94 (VDDA)
/Capacitive Touch (Optional)/VDDD: C403.1, C404.1, TP411.1, U401.17 (VDDD), U401.75 (VDDD)
/Capacitive Touch (Optional)/XTALN: C405.1, R409.2, U401.70 (XN), X401.1
/Capacitive Touch (Optional)/XTALP: C408.1, R409.1, U401.71 (XP), X401.2
GND: C401.2, C402.2, C403.2, C404.2, C405.2, C406.2, C407.2, C408.2, C409.2, J401.32, J401.33, J401.SH (SHIELD), J402.37, J402.SH (SHIELD), R402.2, R405.2, U401.18 (VSSD), U401.19 (VSS), U401.46 (VSS), U401.66 (VSSA), U401.72 (VSS), U401.76 (VSSD), U401.82 (TEST), U401.95 (VSSA), U401.114 (VSS), U401.PAD (GND); also elsewhere on the board
unnamed: R401.1, TP401.1, U401.81 (~RST)
unnamed: TP405.1, U401.84 (GPIO7/~INT)
unnamed: TP407.1, U401.85 (GPIO6/WAKE)

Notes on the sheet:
Crystal (req for USB operation)
Decoupling
Touchscreen Connectors
LHS
RHS
To test non-USB operation: - Remove R406, place R405 to pull PSEL low - Place 0 ohm jumper R407 between VDD3 & 3.3V - Remove VBUS inductor L401
Datasheet doesn't specify what to do with unused inputs/outputs. I think we probably ground these, but leaving this here to experiment.
Optional CapTouch Interface
Note: both TX and RX order is reversed for easier routing. Should mean X and Y axes are reversed in reaback.

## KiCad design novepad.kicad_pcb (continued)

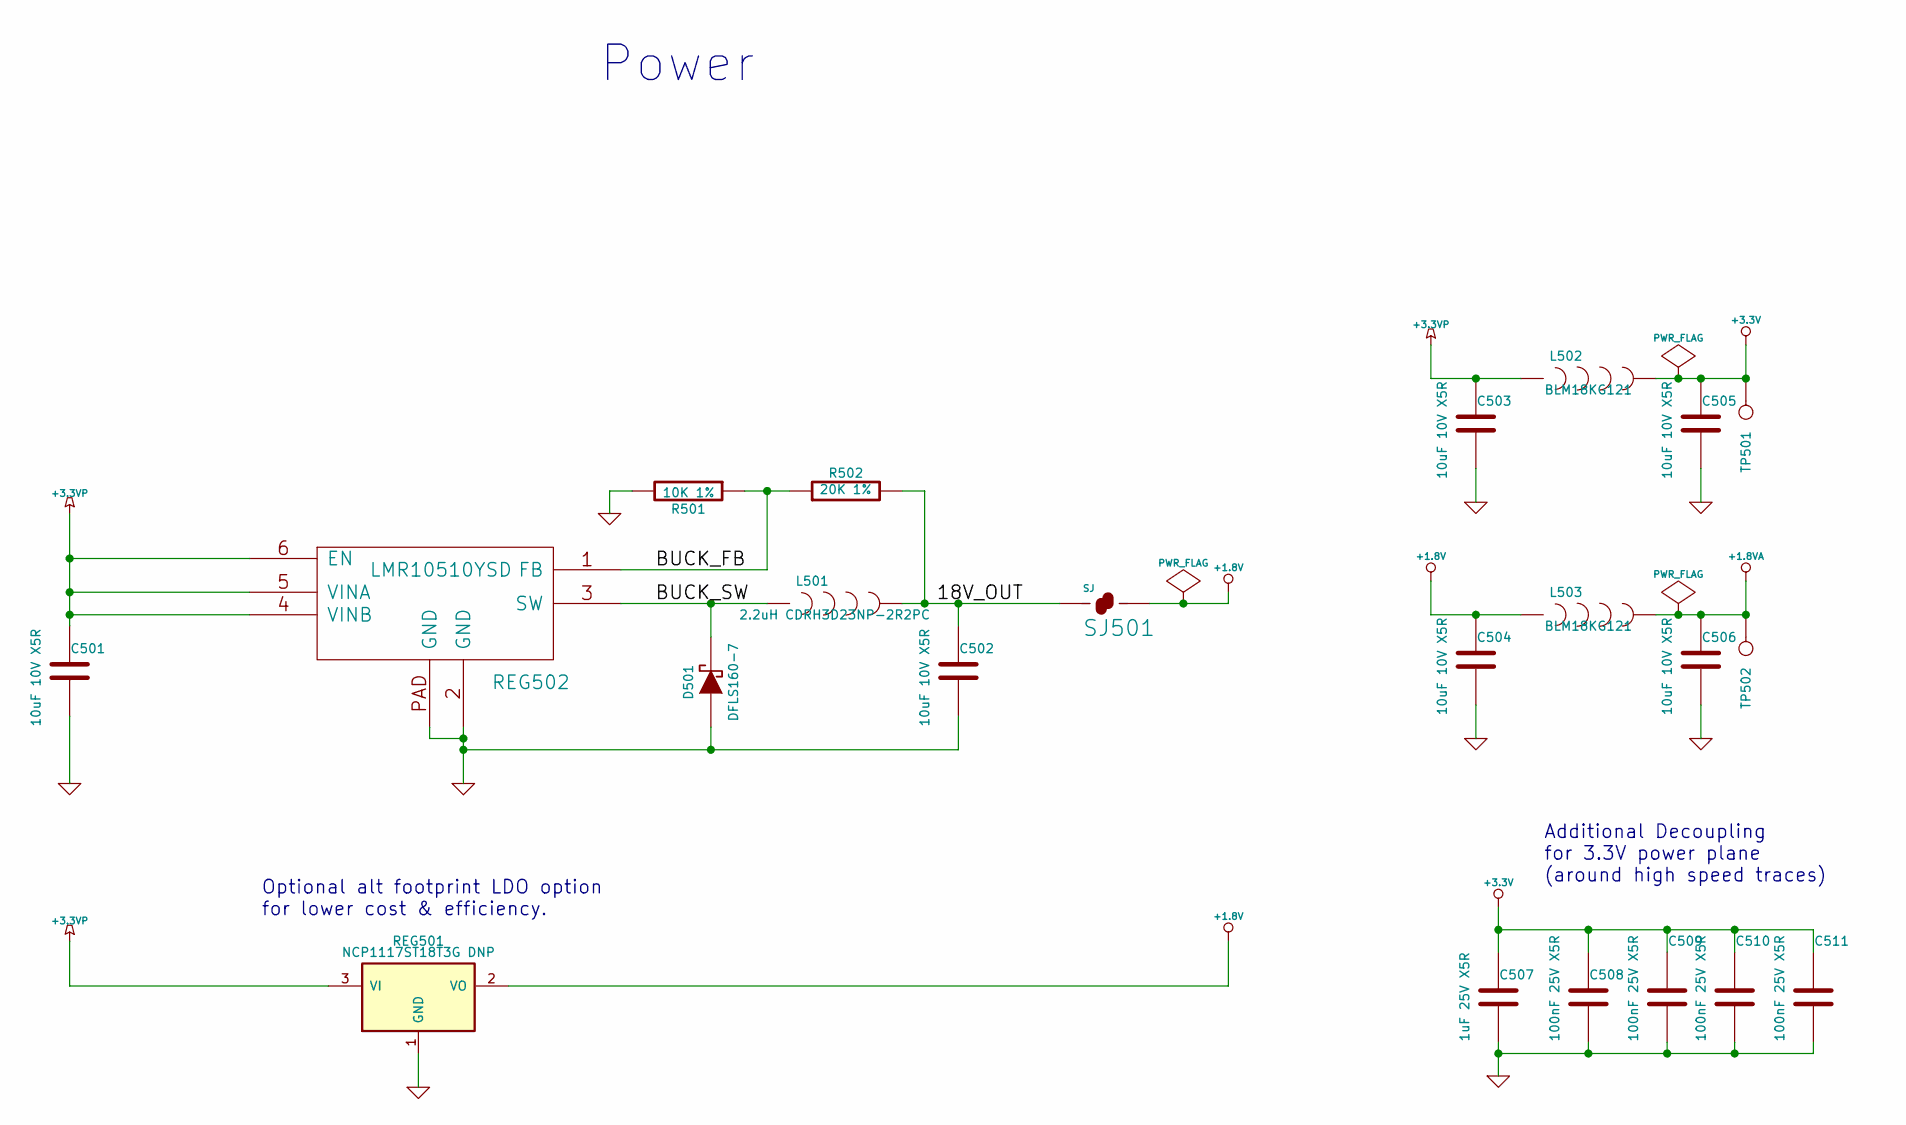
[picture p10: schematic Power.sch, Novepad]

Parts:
C501, C502, C503, C504, C505, C506: 10uF 10V X5R; 1206
C507: 1uF 25V X5R; SMD-0402_c
C508, C509, C510, C511: 100nF 25V X5R; SMD-0402_c
D501: DFLS160-7; POWERDI123_DIODE
L501: 2.2uH CDRH3D23NP-2R2PC; CDRH3D23_IND
L502, L503: BLM18KG121; 0603
R501: 10K 1%; 0603
R502: 20K 1%; 0603
REG501: NCP1117ST18T3G DNP; SOT223
REG502: LMR10510YSD; WSON6
SJ501: SJ; SJ_SHORTED
TP501, TP502: CONN_1; SMD_TEST_POINT

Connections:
+1.8V: C504.1, L503.1, REG501.2 (VO), SJ501.2; also elsewhere on the board
+1.8VA: C506.1, L503.2, TP502.1; also elsewhere on the board
+3.3V: C505.1, C507.1, C508.1, C509.1, C510.1, C511.1, L502.2, TP501.1; also elsewhere on the board
+3.3VP: C501.1, C503.1, L502.1, REG501.3 (VI), REG502.4 (VINB), REG502.5 (VINA), REG502.6 (EN); also elsewhere on the board
/Power/18V_OUT: C502.1, L501.2, R502.2, SJ501.1
/Power/BUCK_FB: R501.1, R502.1, REG502.1 (FB)
/Power/BUCK_SW: D501.K, L501.1, REG502.3 (SW)
GND: C501.2, C502.2, C503.2, C504.2, C505.2, C506.2, C507.2, C508.2, C509.2, C510.2, C511.2, D501.A, R501.2, REG501.1 (GND), REG502.2 (GND), REG502.PAD (GND); also elsewhere on the board

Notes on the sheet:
Optional alt footprint LDO option for lower cost & efficiency.
Power
Additional Decoupling for 3.3V power plane (around high speed traces)

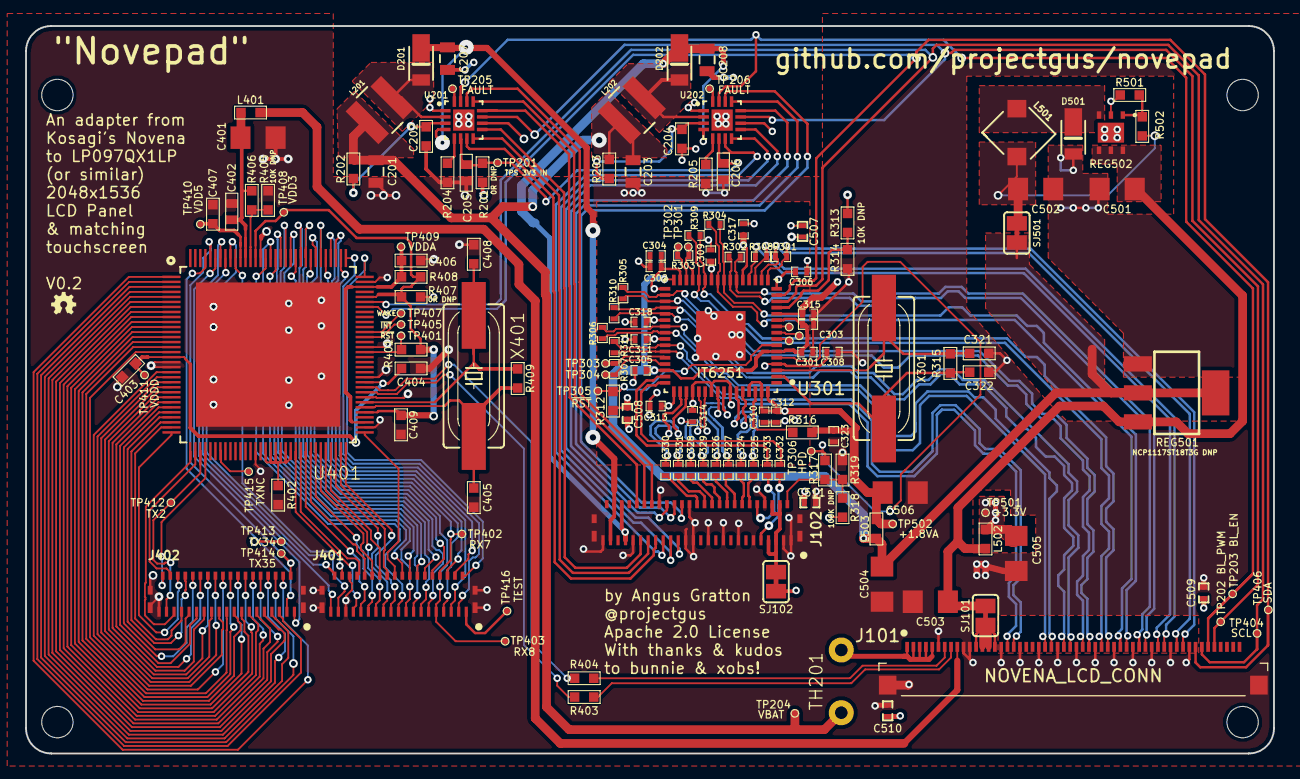
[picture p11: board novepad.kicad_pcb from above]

Board: 4 copper layers, 99.5 x 58.0 mm, 155 parts (0 on the bottom side), 180 nets.

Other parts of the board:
LOGO_OSHW_silkscreen_2mm: val**; LOGO_OSHW_silkscreen_2mm
STENCIL8_HOLE, STENCIL8_HOLE#2, STENCIL8_HOLE#3, STENCIL8_HOLE#4: VAL**; STENCIL8_HOLE

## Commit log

2014-10-23 Initial schematic
    [Backlight.sch, LVDS2eDP.sch, Power.sch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]
2014-10-23 Add schematic PDF, schematic PDF generating script(!)
2014-11-03 Swap fault/slow start FET for inrush current limiting thermistor
    [Backlight.sch, novepad.sch]
2014-11-03 Schematic notes
    [Backlight.sch, LVDS2eDP.sch, Power.sch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]
2014-11-03 Add initial new footprints
2014-11-03 Inductor choices
    [Power.sch, captouch.sch]
2014-11-03 Add shield pin to Novena LCD connector
    [novepad.sch]
2014-11-11 Initial footprint association, last few footprints
    [Backlight.sch, LVDS2eDP.sch, Power.sch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]
2014-11-11 Paper-checked connector layout
    [Power.sch, novepad.kicad_pcb]
2014-11-17 First attempt at routing the high speed differential traces
    [Backlight.sch, Power.sch, captouch.sch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]
2014-11-18 Super-zealous length matching version
    [Backlight.sch, LVDS2eDP.sch, Power.sch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]
2014-11-28 Routed, passes DRC
    [Backlight.sch, LVDS2eDP.sch, Power.sch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]
2014-11-28 Fix gerber defaults
    [novepad.kicad_pcb]
2014-11-29 Update silkscreen, check solder paste layers
    [novepad.kicad_pcb]
2014-11-29 Minor pcb cleanups
    [novepad.kicad_pcb]
2014-11-30 More cleanup, Stencil8 mounting holes
    [captouch.sch, novepad.kicad_pcb]
2014-11-30 More cleanup
    [Backlight.sch, LVDS2eDP.sch, Power.sch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]
2014-12-01 Fix characteristic impedance, no longer require 4/4 trace/space, as per notes in README
    [novepad.kicad_pcb]
2014-12-01 Add 4 additional 3.3V decoupling capacitors for the 3.3V power plane
    [Backlight.sch, LVDS2eDP.sch, Power.sch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]
2014-12-01 Bump schematic PDF
2014-12-02 Reroute tight loop for V0.2, redo length matching with tighter constraints (not for any particular reason)
    [novepad.kicad_pcb]

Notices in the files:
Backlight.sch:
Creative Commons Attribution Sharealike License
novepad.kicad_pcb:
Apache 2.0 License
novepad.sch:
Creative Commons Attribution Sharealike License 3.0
